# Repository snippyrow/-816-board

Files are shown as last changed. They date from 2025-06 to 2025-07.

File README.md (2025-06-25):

# Retro computer board!


A retro computer motherboard for the W65C816S CPU.
Dual-core expandable, 16mb extended memory, four expansion ports.

## *WHY* did I make this??
I have always loved building things with my hands, especially electronics things. I also love computers, and always to learn how they work. I believe that this is part of that hobby, building myself a computer system to play around with. I want to develop software, as well as expandable hardware. My end goal is to write a complete opertaing system for this build, and have it run DOOM!

# Basic Specifications
The primary core is a W65C816S microcontroller, with 32kb of SRAM. EEPROM Space is only accessible to the primary controller. Each core has its own cache, or SRAM chip. Located in the upper-half of the first page, each is 32kb. If the primary controller wants to access EEPROM, I.E. to copy data to another portion of memory, it only needs to access the lower-half. If the primary wants to access the secondary core cache, it uses the expanded memory space. There are two types of busses: core-only and global. The global bus is arbitrated between the two cores. The primary gets priority, then the secondary. In order for the first to access secondary, it must first disable the secondary core. This allows it to always be able to write. The primary core must not access the secondary core too often, as it must be disabled beforehand. If the secondary core needs to access the main bus, it queues to wait before the primary CPU does an internal cycle. At that moment it will take whatever is in the queue registers. This means that the secondary must not access the main memory too often. The secondary cache is only exposed to the global bus if the primary is using it for a transfer. 

The system is powerful enough to run a basic operating system, and provides options to expand into a workable computer system.

## Advanced
The system uses two cores, the W65C816S core. It is not a drop-in replacement for the W65C02S, and samples data during the falling edge of the PHI2. Each core starts in a 6502-emulation mode, and then transitions to the native '816 mode. Each core can access up to 16MB of memory and has 16-bit internal registers. The primary core contains 32kb of EEPROM space as well as 32kb of SRAM space. The secondary core is disabled at runtime, and must be re-enabled later. The low 65kb of the memory (2^16 bytes worth) are used to communicate and run simple programs. The 32kb space acts as a sort of cache system for each core, and they can communicate largely based on the upper shared memory. Beyond the low 65kb there are devices and expansion memory. The secondary core is unable to reach the primary core, though the primary core can access the secondary core by an expansion device. The first devices after the local memory are the expansion devices. Not only are the expansion ports physically on the board mapped here, but so is the control register for the secondary core, as well as the built-in serial port controller. 

While the primary core is not actively using the global/shared memory, the secondary core is free to do so. To upload a program or start a second process, the secondary core must first be disabled and reset. Then, the cache is accessed and the program is copied. The reset vector will point to some location in the cache, and it will be re-enabled. **Do not set the reset vector elsewhere.**
As stated previously, when the secondary core needs to access shared memory, whether that be an expansion device or general memory, it latches the address. If reading, it sets a control bit and waits for a NMIB. If writing, it sets the control but the other way and latches the write data. When the write is completed, I.E. once the primary is not active, a NMIB signal is sent signaling that the memory transaction was completed. The WAI (wait for interrupt) can be used. 
The system is based off an expanion-type model, where it encourages expansion devices to be built and used. Some examples could be a VGA card, sound card, or a keyboard/mouse system.



## Primary core operation
The core is initiated during a power-on reset phase. The secondary core is disabled during this time, and no secondary transactions are happening. The primary will disable the built-in serial port built in directly to the secondary, and can work without using the secondary core at all. It can use the global bus like the internal core bus.

## Secondary core operation
There are two bits that control the secondary core: ENABLE (0) and RESET (1). The ENABLE bit is used to turn the core on or of. It uses the RDY pin to do this. Enabling this also allows the queue to begin transferring data. The IRQB pin is used for the serial adapter, and the NMIB is used when an external read request has been completed. The RESET pin is used to control the RESB pin on the secondary, to reset it to a known state. It is recommended to disable the core using the ENABLE bit before changing data on the secondary cache. When the primary CPU goes into an internal cycle, it takes whatever value is in the address latches and will attempt a memory transaction. The only accessible area for the secondary is the expansion planes and the expanded memory lanes. The RWB bit will control whether it is reading or writing. Since this all takes a single cycle, timing does not matter. The secondary should not attempt frequent external writes due to speed limitations. The secondary only has access to up to half the expandable memory space, as the last bit is used internally for deciding whether it is reading the MMU register. A NMI also happens after a write, to tell the core that the write succeeded before overwriting the register again.

## Built-in serial adapter
The built-in serial adapter is wired directly to the secondary core IRQB pin. If it should be disabled, it can be done so by accessing the internal registers. It uses the R6551 chip. Does not include RS232. When reading data from the serial port, it must use the R6551 as an expansion device, located in the external memory lane. This is so that it can be externally controlled by the primary core. Attempt to read by accessing the global data bus, and wait for an interrupt on the NMIB pin. WAI can be used. The same goes for sending data.
The secondary should rely in the WAI instruction to manage external reads and writes, but could also be triggered by an IRQB signal from the serial adapter. Internal control should be programmed to prevent this. NMI has priority, after that an IRQB will be sent. The flow should be as follows: first an IRQB signal is sent, then an attempt to read the device will be followed by a NMIB signal. When a NMIB is sent during the IRQB routine, it will cause a nested interrupt to occur, allowing it to service properly. 


# Timing Control
Timing control is critical for this system. When PHI2 (the clock) goes from high to low, it indicated the start of a new cycle. VDA/VPA pins change about half-way during the PHI2 low period, and indicate whether the CPU is undergoing an internal cycle. Write and read cycles are all sampled on the falling edge. When VDA/VPA update shortly after the falling edge, the primary core is disconnected from the global bus, and it prepares to do a transaction by updating the address that was latched before. write data is also placed onto the data bus if necessary. On the next falling edge, data is written or data is read. If read, it then sends a NMI to tell the core that it read the data. From there it will read the data back from a specific register. When using it to read, it does not exactly read directly from the memory devices. Instead, it reads from a memory management unit that waits for the primary core to open. The secondary can read the MMU register, located in the upper half of the expandable memory space (bit 23). In order to disconnect the primary, BE is set high, disconnecting the data and address busses. Afterwards, the latches are turned on. 
Immediately after the bank address is pushed to the data bus, all read data begins to enter through either the cache space or the shared memory space. RDY is toggled by the control of the first bit in the control register, and is only sampled and updated on the following falling edge of the PHI2.

## Examples
If the primary wants to upload something to the secondary, I.E. change the task, it will first disable the core and push it into a reset. This prevent erroneous memory accesses. Then, with the cache mapped as an expansion memory device, begins accessing. The primary is **blocked** from accessing the secondary cache if the core is active. The only way for the two to communicate is through the shared global memory tables. After it is completed, re-enable the secondary.

# Expansion Ports
The machine contains four expansion ports, wired directly to the primary. Two of the slots are larger, and each one of the two is either wired to IRQB or NMIB. The other two are simply expansion devices. The larger ones have A0-A3, and the smaller ones have A0-A1 as register addresses. The shared memory on the global bus is beyond the 65K from the two cores.
The controller for the secondary, the controller for the serial port, and just about everything else is connected in through the expansion device encoder to save on space.

# Physical Board Explaination
### Primary Core
The primary core uses the W65C816S, with a 24-bit address bus and an 8-bit data bus. The highest byte of the address bus (A16-A23) is pushed onto the data bus during the low phase of PHI2, and is latched at the rising edge of the clock. The address bus comes stable around the same time. During these times, all the chips may stabilize into selecting the correct hardware for the write. Each core has a 74HC373 and a 74HC245 to moderate the data bus and the banked address busses. The BE pin will set the data bus, address bus and RWB pins to high-Z. The banked address byte is fed into a chip that detects if it is anything >0x00. This means that an external cycle is being attempted. If not, the selection uses A15 to select from either RAM or ROM to read/write from. In an external cycle, the primary is shut off from the rest of the device. During an external cycle, the full address is passed to the global address bus, and the data is either passed through from the data bus directly or read in through an octal buffer. The RWB pin is multiplexed along with the secondary.
The expansion slots are wired directly into the primary core NMIB/IRQB pins, and are pulled high on the board. 

### Secondary Core
The secondary core has much the same setup as the primary core, but has some key differences. It can work independently of the primary through its own cache, but lacks an EEPROM space. In order to perform an external read/write, when it detects an external memory transaction it always writes to a large set of registers. These registers latch A0-A22, as well as whether it wants to read or write. It may not be necessary for it to use the full 16MB address space. The secondary cache lies outside of the range that the secondary can reach. When it is latched, it also sets a D-flipflop into a HIGH state. The state of the first flip-flop is transferred over to the external memory device selector, which can choose which device to enable. It is only active during either an external cycle made by the primary or the secondary waiting to write/read data. Now that the devices have a stable address, when an external cycle happens, it sets the second flip-flop into a HIGH state. This will immediately reset both back to LOW, but sends a NMI to the secondary processor.
During an external cycle, the secondary processor latches are always pushed out to the global bus, as well as any data. If no core is desiring to read from the global data bus, then it may go floating. If the secondary desired to write previously, that old data would be pushed, otherwise nothing holds on to the data bus. Therefore the global data bus is always pulled LOW.
A15 is always pulled LOW, and in order to *read* data coming from the global busses, any address from 0x0000-0x7FFF will work. It simply takes the place of the EEPROM space. On the secondary the cache is in the upper half rather than lower.
The secondary processor has two control bits, ENABLE and RESET. ENABLE will control the processor state, pausing it and disabling the address/data busses. The RESET bit will cause it to reset back to a known state. The secondary processor will have all of its data and address busses disabled during this time. The cache can be accessed by the primary core processor during this time, while it is disabled. *It cannot access while running.* While the address and data busses are in a High-Z state, the cache can be selected as an expansion device, and the address/data/RWB for the primary processor are pushed in. The secondary local data bus are always pulled LOW. The secondary address bus is always matches the primary address bus while not enabled, as a way to drive it.

#### Serial adapter
As mentioned earlier, the serial adapter is wired directly to the secondary core, and works as any other expansion device would. The secondary should either disable the adapter or mask interrupts if it were to be doing something other than serial work.

#### Memory selector
The memory selector works entirely off the global address busses for selection, choosing serial devices or memory expansion cards. Devices are only selected if either there is an external cycle or the secondary is waiting to write data. 

# Datasheets
https://www.westerndesigncenter.com/wdc/documentation/w65c816s.pdf

# BOM
| Item | Quantity | Price (USD) |
|---|---|---|
| JLCPCB 180x140mm | 5 | $25.15 |
| 10K Resistor | 10 | $1.85 |
| SN74HC373N Latch | 10 | $9.77 |
| W65C816S6PG-14 MPU | 2 | $24.20 |
| L78L33 Regulator | 5 | $1.40 |
| 10uF Capacitor | 5 | $1.15 |
| LED (Red) | 10 | $2.60 |
| SN74HC04N Inverter | 5 | $6.55 |
| SN74HC21N Gate | 4 | $2.60 |
| Tactile Switch | 5 | $1.50 |
| SN74HC245N Transceiver | 10 | $6.22 |
| AT28C256 EEPROM | 1 | $11.62 |
| 150Ω Resistor | 4 | $1.44 |
| AS6C62256 SRAM | 2 | $9.50 |
| 1MΩ Resistor | 4 | $1.44 |
| SN74HC138N Decoder | 5 | $5.50 |
| 1N914 Diode | 5 | $0.50 |
| SN74HC10N Gate | 4 | $2.52 |
| 10kΩ Resistor | 20 | $0.30 |
| 1kΩ Resistor | 10 | $0.27 |
| SN74HC32N Gate | 4 | $2.20 |
| SN74HC688N Comparator | 6 | $8.52 |
| 4.7kΩ Resistor | 10 | $0.47 |
| SN74HC126N Buffer  | 4 | $2.64 |
| SN74HC00N Gate | 5 | $3.00 |
| 2N3904 Transistor  | 10 | $0.77 |
| 30pF Capacitor | 10 | $1.18 |
| 0.1uF Capacitor | 100 | $4.00 |
| 1MHz Oscillator | 2 | $6.90 |
| SN74HC08N Gate | 4 | $2.40 |
| SN74HC74N Flip Flop| 4 | $3.60 |
| 20-pin Socket | 24 | $3.10 |
| 16-pin Socket | 20 | $2.42 |
| 14-pin Socket | 20 | $2.20 |
| 28-pin Socket | 6 | $3.84 |
| 40-pin Socket | 4 | $3.68 |

**Total: $167.00**

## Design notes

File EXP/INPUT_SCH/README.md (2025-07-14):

# Computer input controller
Like all computers, I need a way for the user to send input to the machine.

## Features
This device has the ability to send and receive commands to PS/2 devices, including keyboards and mice. To switch between the two, special commands can be sent that are interpreted by both devices.

Two ports are included: one for a keyboard and one for a mouse. May or may not be colroed, but text underneath will specity. Each port has two registers that can be accessed by the system, as well as a status register:
| Vector | Name |
| --- | --- |
| 0x0 | KBD Send |
| 0x1 | KBD Recv |
| 0x2 | Mouse Send |
| 0x3 | Mouse Recv. |
| 0x4 | Int. Status |

When either a keyboard or mouse port receive a packet, it sends a signal along the IRQB line on the main core. If it misses a packet, it will be overwritten with the next one and cannot be recovered. The interrupt status register is as follows:

`ECCCPPMK`

The first bit read from this register declares whether the keyboard has sent the interrupt. The next bit declares if the mouse has sent the interrupt. If both are high, then both devices have sent the interrupt at the same time. If this happens, both packets are preserved in each register. The third bit in each register is the result of each parity bit from the ports. It is also overwritten on the next packet. The third bit is for the keyboard parity, and the fourth is for the mouse parity. If a parity errors happens, send another command to the respective device to re-send the command.

When reading each received packet data register, the interrupt returns to zero in the status register. For examples, reading 0x1 makes the first bit go to zero.
Sending commands happens in hardware, without need for system intervention. The PS/2 clock signal for each port is derived from the system clock, being divided by a value selected in the three C bits. These three C bits are the only writable bits in the control register, and go towards a decoder. It can select from 1/16 system speed up to 1/2048 speed. This is important because this system can take advantage of a wide range of clock speeds, and this would mess with the PS/2 bus speed. It must be around 10-20khz. If the divisor is set larger, then the host must write commands slower. If it takes 11 bits per packet, at 16 block cycles per bit, then the host must not send another command for 176 clock cycles. For 1mhz (1/64), that increases to about one every 700 cycles.

The host CAN send a command to a mouse within this timeframe, and both are sent and received independantly.

The E bit in the control register can be set to 0 to disable the input card, which is set to at default. This disables the IRQB line on the card, allowing another device to use it if needed.

Receiving packets happen asynchronously, as the CLK/DATA lines are usually pulled high by a resistor. When CLK first goes low, it triggers a capacitor to quickly charge and slowly discharge. Data is latched on each clock falling cycle, into a shift register. There are two 8-bit registers to hold all of the bits (11), and the parity bit is outputted in the control register when read. After the packet is completed, the capacitor will discharge and set a latch. This is OR'd with keyboard/mouse latches, so both must be acknowledged before the line goes dead. Sending commands also happens over hardware. Data is written into the register by the system, and a counter is reset. Two decoders are set to send the start bit, packet byte, parity and stop bit. Probably will be two 74HC238's. After the counter is over a certain value (11), the bus stops pulsing the CLK signal and the DATA bus is permanently released. The counter is ticked on every divided clock pulse. Pairty is computed in hardware against the contents of each input register automatically. By the time all the bits are sent, the parity computation will be completed. Parity is computed against an 8-bit number using eight XOR gates, or a single 8-input XOR gate.

Alternativly, use a 74HC280 to generate odd parity. It implements everything internally. In order to handle the counter properly, implement a 4-input NAND or AND gate to check 0b1010 (10) and stop the counter from going any further. ALso run that to block the CLK from being changed. Data should be updated on the DATA bus after the rising edge of the CLK and will be latched by the device during the falling edge.

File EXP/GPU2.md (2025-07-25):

# What happened??
The timings may be too tight with the original design, being forced to act in under 20ns. The fix is that instead of using each VGA pixel cycle to write data and preload, use four cycles to write and four to preload. This is good because it has MUCH longer to act, and I can therefore use a more covnentional 128k x 8 SRAM. It can easily act within 55ns, unlike the 12ns one.

## Advancements?
The first half of the 8-cycle period is for writing data. The multiplexers are set to the addresses in the registers, and a writing state is initialized. This will take upwards of 40 x 4ns, or 160ns. This is well within the allowed time. When powering up the card, the preload register is initialized to 0x00. The preload phase is on the other half, directly controlled by X2. WHen in the preload phase, it is set to read mode, and the address is switched to the counters. At the same time, the latch is enabled, allowing the data to be laoded. Since this is technically happening half way through the byte, everything will be shifted over some. To prevent the slow access time from bugging out some pixels, the data is only committed at the last cycle. Software should be able to counteract this.

## What works?
The signal generation works well, as it is within the allowable timeframe. I suspect that the main cause was the slowness of the 74LS20 chip, though I can't know for sure. The only way to test it for certain is to buy a 74HC/AC20 and plug it in. Overall the timing may be too restrictive for these chips, and in that case it may be worth it to simply convert over to the less harsh design. It may use more board space however, specifically around the control section. If the user decides to change the X/Y coordinate immediatly before the writing of the data, and a timing contention happens, nothing bad happens. If the address is late, it will simply write the old data into the new location. It will almost instantly be overwritten next phase.

## Extra parts
The previous design used a NAND and a 4-input NAND to control the operation. Instead, Alternate read/write cycles by using X2, which should be fast enough. A 3-input AND gate can be used to time the latching circuit, taking in X0, X1, X2. it would it irrespective of the clock phase.

## Conclusion
The write phase will not collide with the read phase at all, and this allows for better timings. Since each stage has 160ns to act, that is WAY more than enough time to work. The main focus is the preload time, which is arguably the most vital step. It allows three cycles, or 120ns, to read. This can then be latched, and since it is mostly irrespective of clock, takes 40ns. This is good enough. Things will be shifted over by one, since it will technically be loading the previous set of pixels and then displaying them later. Either software can shift, or nothing happens at all. Everything is shifted over by 7-8 pixels, and it should be basically invisible to the user.

# Oscilloscope

The oscilloscope likes to smooth off bad edges, and timing issues are a major cocern. It may not be rated for these sorts of speeds, though should do fine for now. The circuit works in theory, but in practice the timings are impossible.

## Practical circuit application
The signal generator will be exactly the same as before. Six comparators get the start and end of each sync pulse, as well as the time tk reset to the Y counter. These go into a flip-flop, to maintain the state of each sync pulse. They also go into inverters for the counter control logic. The counters are updated on the falling edge of the vga clock. The registers are also the same, as timing is not an issue. A 74HC238 decoder is updated for each one, and is managed by the device select, PHI2, and the RWB signal. The multiplxers for the address are tied between the pixel counters and the user-defined locations. These are always outputting and are controlled by the X2 bit. If X2 is low, enable the user-defined registers. Otherwise, define the pixel counters during preload. These technically change every 160ns, giving the SRAM plenty of time. The SRAM is an HM628128 with a 55ns access time. Both chip selects are ON, and it is toggled between OEB and WEB. OEB/WEB signals are defined by the X2 bit again, so it is always complimentary and very stable. A three-input AND gate is used to control the latching of the preload register, and that register feeds in to an 8-1 multiplexer. That is controlled by X0, X1, and X2. The frame select is not time-dependant that much, and the architecture can be carried over. The only difference is the added latch enable controller, which uses a 3-input AND. When the clock goes over into the next byte, latching is disabled and the addresses are switched. Since it is controlled directly by fast counters, the latch should disable itself faster than the addresses are able to switch over.

## Action
Test for any other abnormalities, order a 74HC20 or 74AC20. While doing so begin construction on the new design using breadboards. Signal encoders make 3 boards, ram/output logic makes 1, everything else 1 so five boards. Use jumpers to build, test each one for connection issues.

## NEW
The timing will work slightly differently now. Each pixel cycle is roughly 40ns, and the RAM has a 55ns access time. The address is not looked-ahead at all, to save board space. During the first-half of each byte cycle, the CPU has access to write data to the RAM. During the second half, the video circuitry has access. Since the data is only latched at the last pixel cycle, the data displayed will be eight pixels dragged forward. This results in a thin black section on the left, and some text going off on the right. This can be corrected in software. During the first cycle, AKA when X0-X2 is 0b000, the SRAM is switched into a writing mode.

On the first cycle the address bus is changed to the correct data, and the data bus is updated. At the same time the OEB bit is set HIGH. During the second cycle the WEB bit is set LOW. This state repeats for another cycle. During the fourth cycle the WEB bit goes HIGH, and the OEB bit goes LOW. The data bus will disengage as well. On the fifth cycle the address bus will change to the pixel address that is required. On the eighth cycle the data is latched into the 74HC165 register. This will lead right into the next byte cycle, where OEB goes HIGH. The counters are updated on the FALLING edge of the pixel clock!

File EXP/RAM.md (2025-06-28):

# Expansion RAM Module



## What is it?
This is a special module made for my custom motherboard. It can hold exactly 2^21 bits of information, or around 2MB. The motherboard has space for two of these modules, adding up for a total of 4MB. USing the breakout pins, up to 16MB can be added. The board would just be too large.

## How does it work?
The module contains four AS6C4008 SRAM chips. Each one has an access time of about 55 nanoseconds, making it quite fast. Each chip can store 512KB of data, four of them adding up to 2MB. It works virtually the same as the cache memory directly soldered to the motherboard, just larger. The controller system is also quite simple. One first chip is a 74HC138, which selects the correct chip in the module. It uses pins A20-A21 to define which one it needs. The second one controls whether to read or write from the selected chip. as defined by the PHI2 and RWB pins on the expansion slot. It also comes with a large capacitor built into the module. As to prevent random data los due to pwoer fluctuations. While each memory chip has built-in protections, it's best to use extra security if there is enough board space. It also comes with a power LED, telling the user the right orientation and whether it's connected to power.

## How do you use it?
The module expands away from the expansion cards, which are themselves supposed to stretch backwards. That way, they don't hit each other during installation! The edge connector I used provides enough friction to hold the cards in place.

## Extra images



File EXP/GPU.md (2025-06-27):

# Custom-made GPU

A standard 640x480 VGA-generating GPU for my computer build, as listed in the parent directory. Having only one bit per pixel for color, this makes it extremely useful for rendering a text display.

## Why did I build this?
I think that every computer should have a graphical output of some form, and this is as simple as it gets. This expansion board will allow me to do a lot of cool things with my project.

## Explaining the inner workings


The card uses a 640x480 60hz resolution, running over a standard VGA cable. This can be converted with a dongle to HDMI or DisplayPort. The card has four registers: pixel location X, pixel location Y, data write register and control register.
Since the card uses one bit per pixel, there can be eight pixels stored in a single byte of VRAM at once. Therefore, you can write eight pixels are once, going left to right. A standard text display has each character being 8x16 pixels in size, so you can perfectly write in each character using 16 different write cycles. The text resolution is 80x30 characters, fitting inside a 640x480 text display. This is certanly not limited to text, just optimized for it. You can use a dithering algorithm to draw in more advanced graphics and images.
The pixel X register actually moves the pixel selector 8 pixels at a time, and you can selectively write bits for each one. It also supports basic double buffering, since it uses a single 128k x 8 SRAM module. 640x480 uses less than half of the space, so the highest-most but is used to select the frame. The user can write to a back frame before switching them. It is then automatically switched at the end of each frame. Pixels are preloaded every eight cycles, and is kept track of using the X counter, which keeps track of which pixel is being displayed at any time. During the first low phase of the clock, the addresses are changed from the user-defined addresses to the ones found in the counters, and the RAM is outputted to store eight pixels are a time. In between these preloading phases the user writes pixel data to the back frame. If the CPU can handle a maximum of 100,000 writes per second to the GPU (very slow), then the actual data is 800,000 pixels per second, and 640 * 480 is about 300,000 pixels. Therefore it is quite fast for a text display, and can easily hit several frames per second on a slow speed. The card automatically generates frames without any user input, is completely asynchronous from the main board and is optimized for holding a frame long-term.

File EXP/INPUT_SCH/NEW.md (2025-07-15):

# Single-port keyboard handler

This is a basic handler for a single PS/2 active keyboard. The device has the ability to both send and receive commands.

The PS/2 bus works as follows: The DATA pin is controlled by both the host and the device, but the CLK pin is usually controlled by only the device.
When reading a packet from the PS/2 device, a capacitor is charged whenever the CLK line goes low. Data is latched on every LOW clock edge, and the capacitor is allowed to discharge slowly.
After the entire packet is sent, the capacitor will begin to slowly discharge.
Once it reaches a certain theshold, the capacitor will activate a signal that will trigger the IRQB pin.
Since the lines for sending and receieving commands are shared, a control system will be implemented to prevent the receiver register from being overwritten. Also to prevent erroneous interrupts.

## Sending packets
Sending commands must be followed by a specific sequence of steps. To begin sending, the host must pull the CLK lane LOW for >100us. To do this, use a monostable multivibrator to pull it low. This is the only time that the host will pull the clock lane low. Usually when a packet is received, it would go through a latch ticking high for a moment, but that action is inhibited at the moment a transaction is started. Due to various CLK speeds, a second capacitor system is set up. At the first clock pulse, and if the writing register is written, a signal goes LOW that inhibits the interrupt register. This has an interval LONGER than the first chain, meaning that no interrupts are triggered. Once it gets re-enabled, it allows it to send interrupts again. As a product of this, the incoming register gets voerwritten by the new data. This should not be an issue, since input registers should always be read from at the moment of an interrupt.

Data is latched by the device on the RISING edge of the CLK lane, and data should be updated on the FALLING edge. A 4-bit counter is for selecting each data bit to send in a packet. There are: START (0), byte, parity, STOP (1). When a write is issued, the CLK lane is pulled. When the interval is over, the counter will have been reset to zero, and it can pull the data ane LOW for the start bit immediatly. SInce the release of the CLK lane will be detected as a rising CLK edge, the counter will try to update to one. Therefore place everything one bit higher than expected. The counter should go into two 8-1 multiplexer ICs, This will select the correct bit to be sent. The counter should be disabled after the packet is sent, as an incoming packet will cause it to roll over and cause contention. Therefore when the counter exceeds 11, disable any future counting. 

## Host parity
PS/2 Uses ODD parity, and a 74HC280 should be sufficient to do this. It is added on after the data byte and is computed immediatly on the contents of the outgoing register. When the system attempts to write data, at the moment CLK is pulled LOW, the counter selecting each data bit is reset. During this initial pull-down phase, the card will not be allowed to pull the data bus.

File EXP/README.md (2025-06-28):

# Custom computer expansion cards!



A collection of expansion cards I plan to build for my custom dual-core W65C816S motherboard. Two examples include: a basic text-based graphics card, and some 2MB RAM modules.

## Why Did I Build These?
A computer without a graphical display, or RAM sticks is pretty useless. You can run some basic algorithms, but that's about it. These pieces of customized hardware will *drastically* improve that this build can do. For more information, please see the parent directory for the main build.

# About
# If you want to see specifics for each expansion card I plan to build, see the directories listed here in this folder.

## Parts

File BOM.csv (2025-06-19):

NAME | QTY# | COST (USD) | SOURCE
PCB – 4 Layer 180mmx140mm JLCPCB | 5 | $25.10 | JLCPCB
0.1uf 1206 SMD Capacitor | 20 | $2.19 | MOUSER
SMD 1206 Diode | 2 | $1.10 | MOUSER
EDGE CONN 24P | 5 | $4.64 | ALIEXPRESS
EDGE CONN 20P | 5 | $4.17 | ALIEXPRESS
1206 SMD 10K RES. | 25 | $2.56 | MOUSER
RESISTOR NETWORK 10K | 5 | $1.83 | MOUSER
W65C816S | 2 | $26.94 | MOUSER
74HC08 | 2 | $1.10 | MOUSER
AS6C62256 | 2 | $10.57 | MOUSER
74HC373 | 2 | $3.59 | MOUSER
74HC245 | 9 | $7.23 | MOUSER
74HC74 | 2 | $3.52 | MOUSER
AT28C256 | 1 | $12.94 | MOUSER
R6551 | 1 | OWNED | N/A
3.3V/5V Regulators | 5 | $1.46 | MOUSER
74HC32 | 1 | $1.42 | MOUSER
74HC688 | 3 | $4.75 | MOUSER
74HC00 | 1 | $1.59 | MOUSER
74HC04 | 2 | $2.92 | MOUSER
74HC14 | 1 | $1.83 | MOUSER
74HC126 | 1 | $1.69 | MOUSER
74HC138 | 2 | $4.12 | MOUSER
74HC10 | 1 | $1.61 | MOUSER
1.8432MHZ | 1 | OWNED | N/A
1MHZ | 1 | $3.69 | MOUSER
SHIPPING | 1 | $14.60 | MOUSER
TOTAL |  | $148.12

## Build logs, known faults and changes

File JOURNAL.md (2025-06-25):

---
title: "65816 Retro Motheroard"
author: "snippyrow"
description: "A retro computer motherboard designed for the 65816 CPU."
created_at: "2025-05-24"
---

# May 28th: Began laying out PCB!

For the past few weeks I worked on the schematic, going from a quad-core to a dual-core architecture. I had to cut back and expand on several ideas, though it all seems to work according to the datasheets!
Snapshot_2025-05-28_17-15-16

Snapshot_2025-05-28_17-15-46

**Total time spent: ~12h**

# May 29th: Finished laying out PCB

Finished laying out the custom PCB. In the process I removed one of the expansion RAM slots to save on board space, bringing the total amount of expandable memory down to 6MB. Additionally I removed the decoupling capacitors connected to the RAM, as I believe they take up too much space and can be easily added to the individual expansion sticks.



**Total time spent: 3h**

# May 31st: Updated PCB Layout Again..

After checking the design voer, I realized that improvements could be made. Added mounting holes around the corners, as well as the implementation of a serial port directly on the main board. While it does not use RS232, it uses an arduino-compatable 0/5V signal. The 4-pin header comes with a 5V supply pin, allowing a device to expand it out to any type of standard required. Serial connects into the secondary core directly, allowing it to take some of the load off the main CPU. Appears like an expansion device on the BUS.




**Total time spent: 3h**

# June 7th: Finished Major Re-design

I discovered an issue in my original design, the system that enabled the secondary processor was faulty and would never enable it properly. I also discovered issues with the way the primary CPU writes data to memory, as it would sample data on the wrong half of each cycle. This would cause severe issues. Additionally I decided to change up the design of the system, giving each processor 32kb of cache. This way each co-processor can work fully independantly of the other, only needing to halt in case it needs to access the global memory bus, which exists outside the first 65k. I also wrote a ton of documentation in the README.md file, which extensively explains how the board works.



**Total time spent: 9h**

# June 11th: Half-way there!

I looked over the entire schematic, checking it twice, and began laying out my new PCB. All good things must come to an end, and it doesn't look as nice as the other one yet. I changed it to use mostly through-hole ICs to make it look more "retro", as well as being easier to prototype with.



**Total time spent: 2h**

# June 13-14th: Almost done..

I spent this time completing the board layout in the kicad designer, as well as checking the schematic again. I found a few small issues and correct them, though I will probably need to check things one more time before completion. I changed it to have only *two* RAM expansion cards, at 2MB each. This leaves it with 4MB of RAM + expansion cards + local cache. I have put everything into an auto-router, which is going as I write this. I think that I will need to spend a lot more time fixing some of the artifacts of the process, though this is *far* faster than doing it manually.





**Total time spent: 4h**

# June 16-18th: FInal checks

I sepent the last bit fixing some minor hardware bugs, as well as completing the PCB layout and tracing. The kicad ERC returns zero errors, so at this point it's pretty much done and ready to run a program. It's been a great journey, and now I just need to do the tedious work of fixing all the autorouting artifcats. This includes right-angled corners and useless trace geometry. I really hope this project works out! The final size is 180x137mm. Unfortunatly checking a project like this for errors takes a lot of time, so more issues may come to light in later revisions.




**Total time spent: 5h**

**June 23rd: A minor upset**
After joining a forum and asking some questions about my design, I realized that I had done some things incorrectly. I was latching data during the falling edge of PHI2, which in hinesight was incorrect. Due to this I had to change some of my labels as well as switching out most 74HC374's with 74HC373's instead. These work better with the regular bus timings. The pins are almost indentical, so it was a quick fix. I also added some stability by making the address decoding logic check the VDA/VPA pins to see if the bus is valid. This will demand a re-layout and new routing run on the PCB, which should not take long. The price for the project should not change much.



**June 24th: COntinuation**
I completed the board layout and routing process, as well as correcting some minor fixes. The board will soon be production ready, the only thing left is to add more comments to the silkscreen layer.




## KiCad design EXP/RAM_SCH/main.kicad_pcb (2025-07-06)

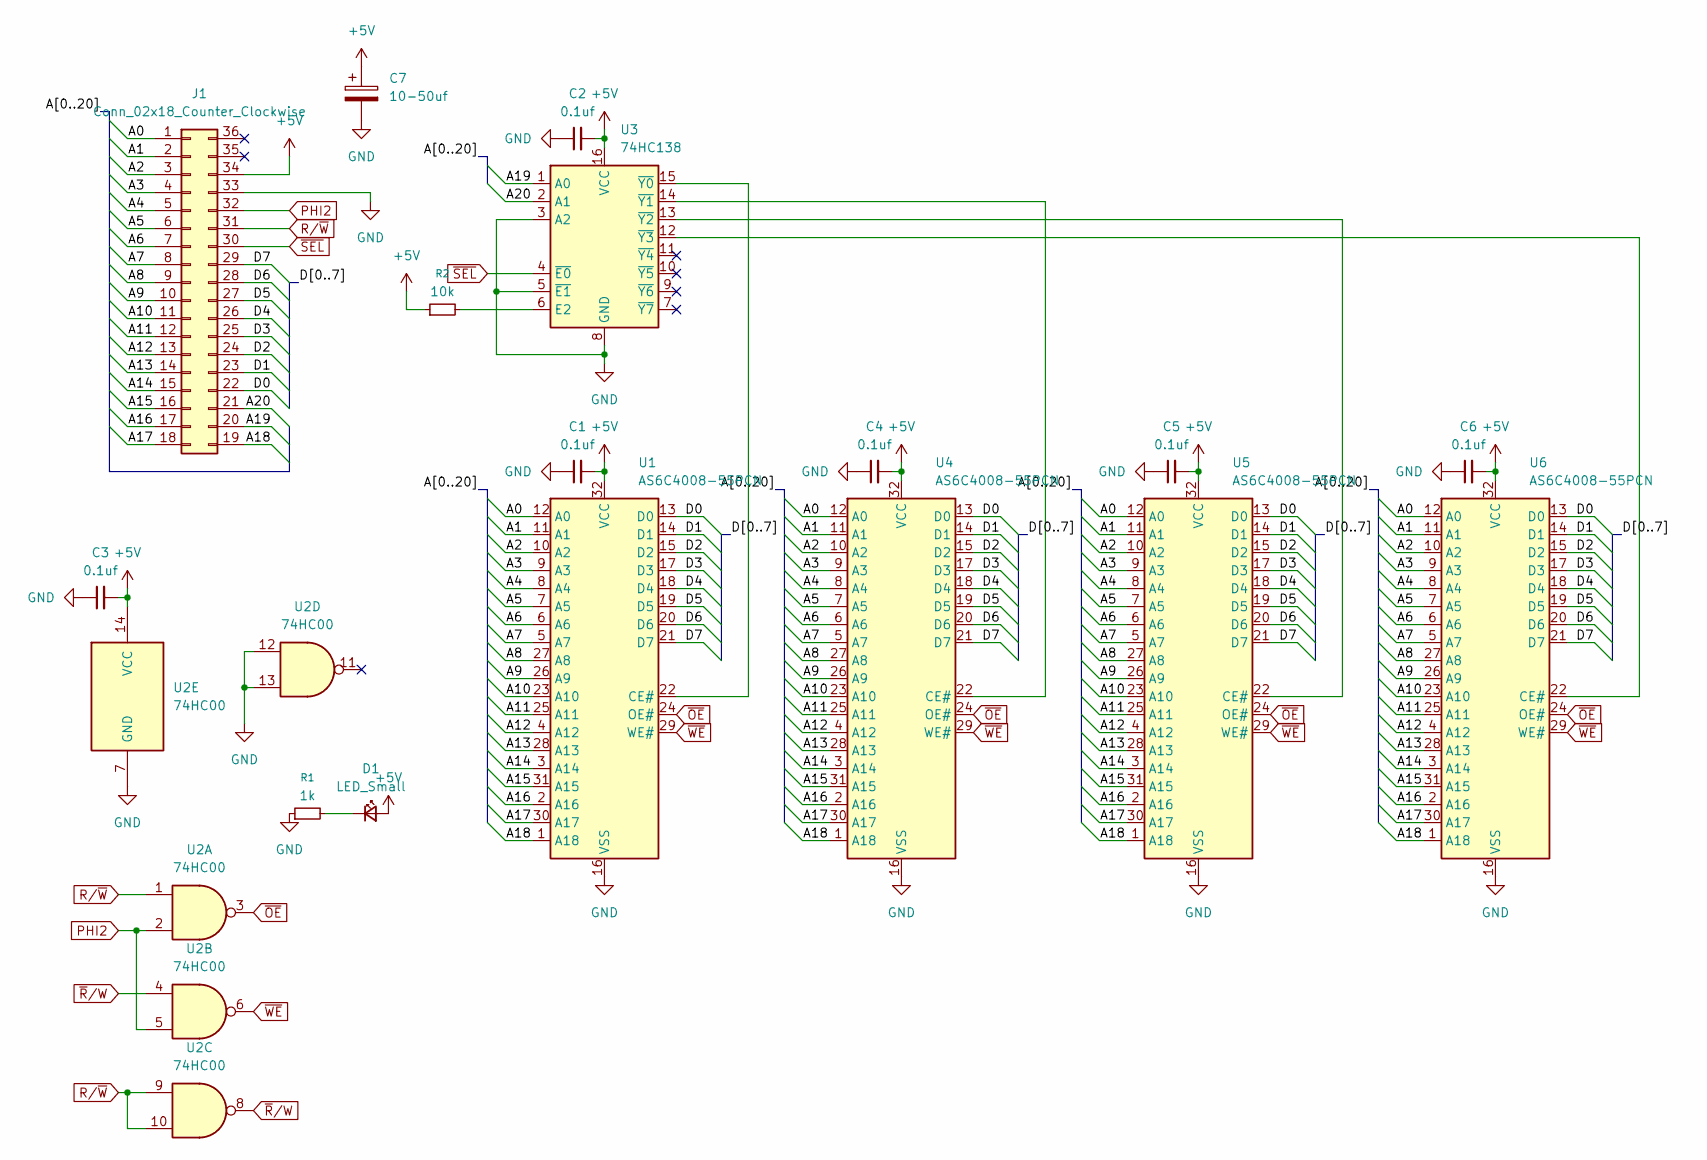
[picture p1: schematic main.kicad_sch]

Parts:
C1, C2, C3, C4, C5, C6: 0.1uf; C_Disc_D5.0mm_W2.5mm_P5.00mm
C7: 10-50uf; CP_Radial_D6.3mm_P2.50mm
D1: LED_Small; LED_D3.0mm
J1: Conn_02x18_Counter_Clockwise; AliExpress_36Edge
R1: 1k; R_Axial_DIN0204_L3.6mm_D1.6mm_P5.08mm_Horizontal
R2: 10k; R_Axial_DIN0204_L3.6mm_D1.6mm_P5.08mm_Horizontal
U1, U4, U5, U6: AS6C4008-55PCN; DIP-32_W15.24mm
U2: 74HC00; DIP-14_W7.62mm_Socket
U3: 74HC138; DIP-16_W7.62mm_Socket

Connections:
+5V: C1.2, C2.2, C3.2, C4.2, C5.2, C6.2, C7.1, D1.2 (A), J1.34, R2.1, U1.32 (VCC), U2.14 (VCC), U3.16 (VCC), U4.32 (VCC), U5.32 (VCC), U6.32 (VCC)
/A0: J1.1, U1.12 (A0), U4.12 (A0), U5.12 (A0), U6.12 (A0)
/A1: J1.2, U1.11 (A1), U4.11 (A1), U5.11 (A1), U6.11 (A1)
/A2: J1.3, U1.10 (A2), U4.10 (A2), U5.10 (A2), U6.10 (A2)
/A3: J1.4, U1.9 (A3), U4.9 (A3), U5.9 (A3), U6.9 (A3)
/A4: J1.5, U1.8 (A4), U4.8 (A4), U5.8 (A4), U6.8 (A4)
/A5: J1.6, U1.7 (A5), U4.7 (A5), U5.7 (A5), U6.7 (A5)
/A6: J1.7, U1.6 (A6), U4.6 (A6), U5.6 (A6), U6.6 (A6)
/A7: J1.8, U1.5 (A7), U4.5 (A7), U5.5 (A7), U6.5 (A7)
/A8: J1.9, U1.27 (A8), U4.27 (A8), U5.27 (A8), U6.27 (A8)
/A9: J1.10, U1.26 (A9), U4.26 (A9), U5.26 (A9), U6.26 (A9)
/A10: J1.11, U1.23 (A10), U4.23 (A10), U5.23 (A10), U6.23 (A10)
/A11: J1.12, U1.25 (A11), U4.25 (A11), U5.25 (A11), U6.25 (A11)
/A12: J1.13, U1.4 (A12), U4.4 (A12), U5.4 (A12), U6.4 (A12)
/A13: J1.14, U1.28 (A13), U4.28 (A13), U5.28 (A13), U6.28 (A13)
/A14: J1.15, U1.3 (A14), U4.3 (A14), U5.3 (A14), U6.3 (A14)
/A15: J1.16, U1.31 (A15), U4.31 (A15), U5.31 (A15), U6.31 (A15)
/A16: J1.17, U1.2 (A16), U4.2 (A16), U5.2 (A16), U6.2 (A16)
/A17: J1.18, U1.30 (A17), U4.30 (A17), U5.30 (A17), U6.30 (A17)
/A18: J1.19, U1.1 (A18), U4.1 (A18), U5.1 (A18), U6.1 (A18)
/A19: J1.20, U3.1 (A0)
/A20: J1.21, U3.2 (A1)
/D0: J1.22, U1.13 (D0), U4.13 (D0), U5.13 (D0), U6.13 (D0)
/D1: J1.23, U1.14 (D1), U4.14 (D1), U5.14 (D1), U6.14 (D1)
/D2: J1.24, U1.15 (D2), U4.15 (D2), U5.15 (D2), U6.15 (D2)
/D3: J1.25, U1.17 (D3), U4.17 (D3), U5.17 (D3), U6.17 (D3)
/D4: J1.26, U1.18 (D4), U4.18 (D4), U5.18 (D4), U6.18 (D4)
/D5: J1.27, U1.19 (D5), U4.19 (D5), U5.19 (D5), U6.19 (D5)
/D6: J1.28, U1.20 (D6), U4.20 (D6), U5.20 (D6), U6.20 (D6)
/D7: J1.29, U1.21 (D7), U4.21 (D7), U5.21 (D7), U6.21 (D7)
GND: C1.1, C2.1, C3.1, C4.1, C5.1, C6.1, C7.2, J1.33, R1.1, U1.16 (VSS), U2.7 (GND), U2.12, U2.13, U3.3 (A2), U3.5 (~E1), U3.8 (GND), U4.16 (VSS), U5.16 (VSS), U6.16 (VSS)
unnamed: D1.1 (K), R1.2
unnamed: U1.22 (CE#), U3.15 (~Y0)
unnamed: R2.2, U3.6 (E2)
unnamed: U3.14 (~Y1), U4.22 (CE#)
unnamed: U3.13 (~Y2), U5.22 (CE#)
unnamed: U3.12 (~Y3), U6.22 (CE#)
PHI2: J1.32, U2.2, U2.5
R/~W: J1.31, U2.1, U2.9, U2.10
~OE: U1.24 (OE#), U2.3, U4.24 (OE#), U5.24 (OE#), U6.24 (OE#)
~R/W: U2.4, U2.8
~SEL: J1.30, U3.4 (~E0)
~WE: U1.29 (WE#), U2.6, U4.29 (WE#), U5.29 (WE#), U6.29 (WE#)

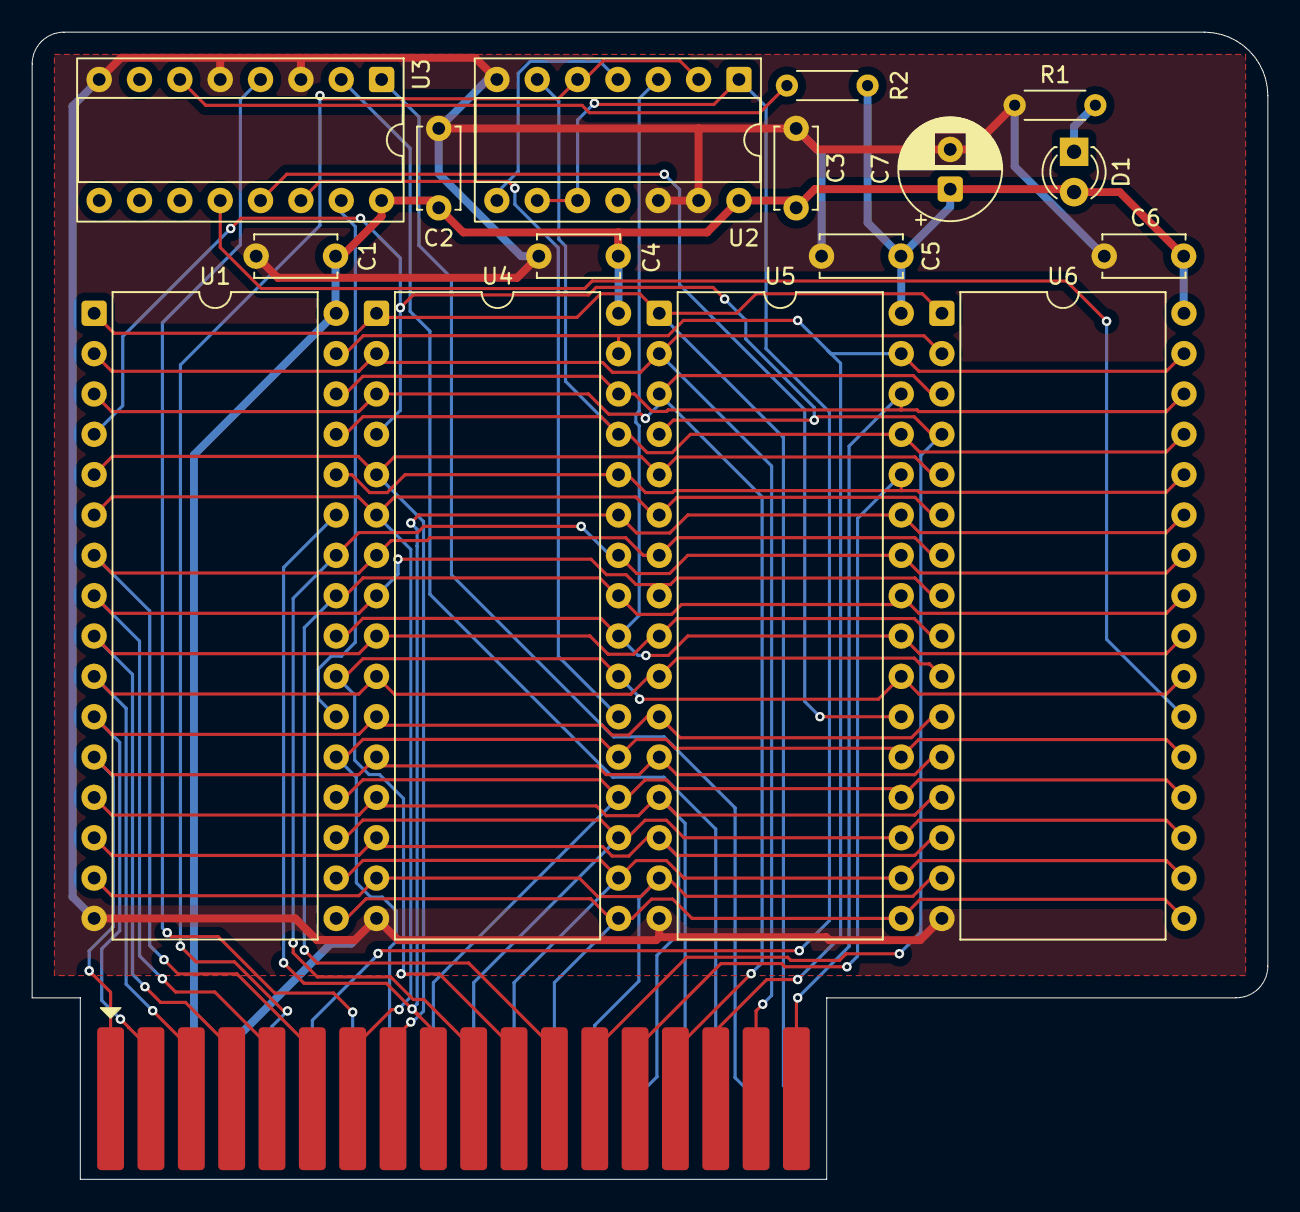
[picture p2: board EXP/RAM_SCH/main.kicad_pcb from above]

Board: 2 copper layers, 77.8 x 72.2 mm, 17 parts (0 on the bottom side), 43 nets.

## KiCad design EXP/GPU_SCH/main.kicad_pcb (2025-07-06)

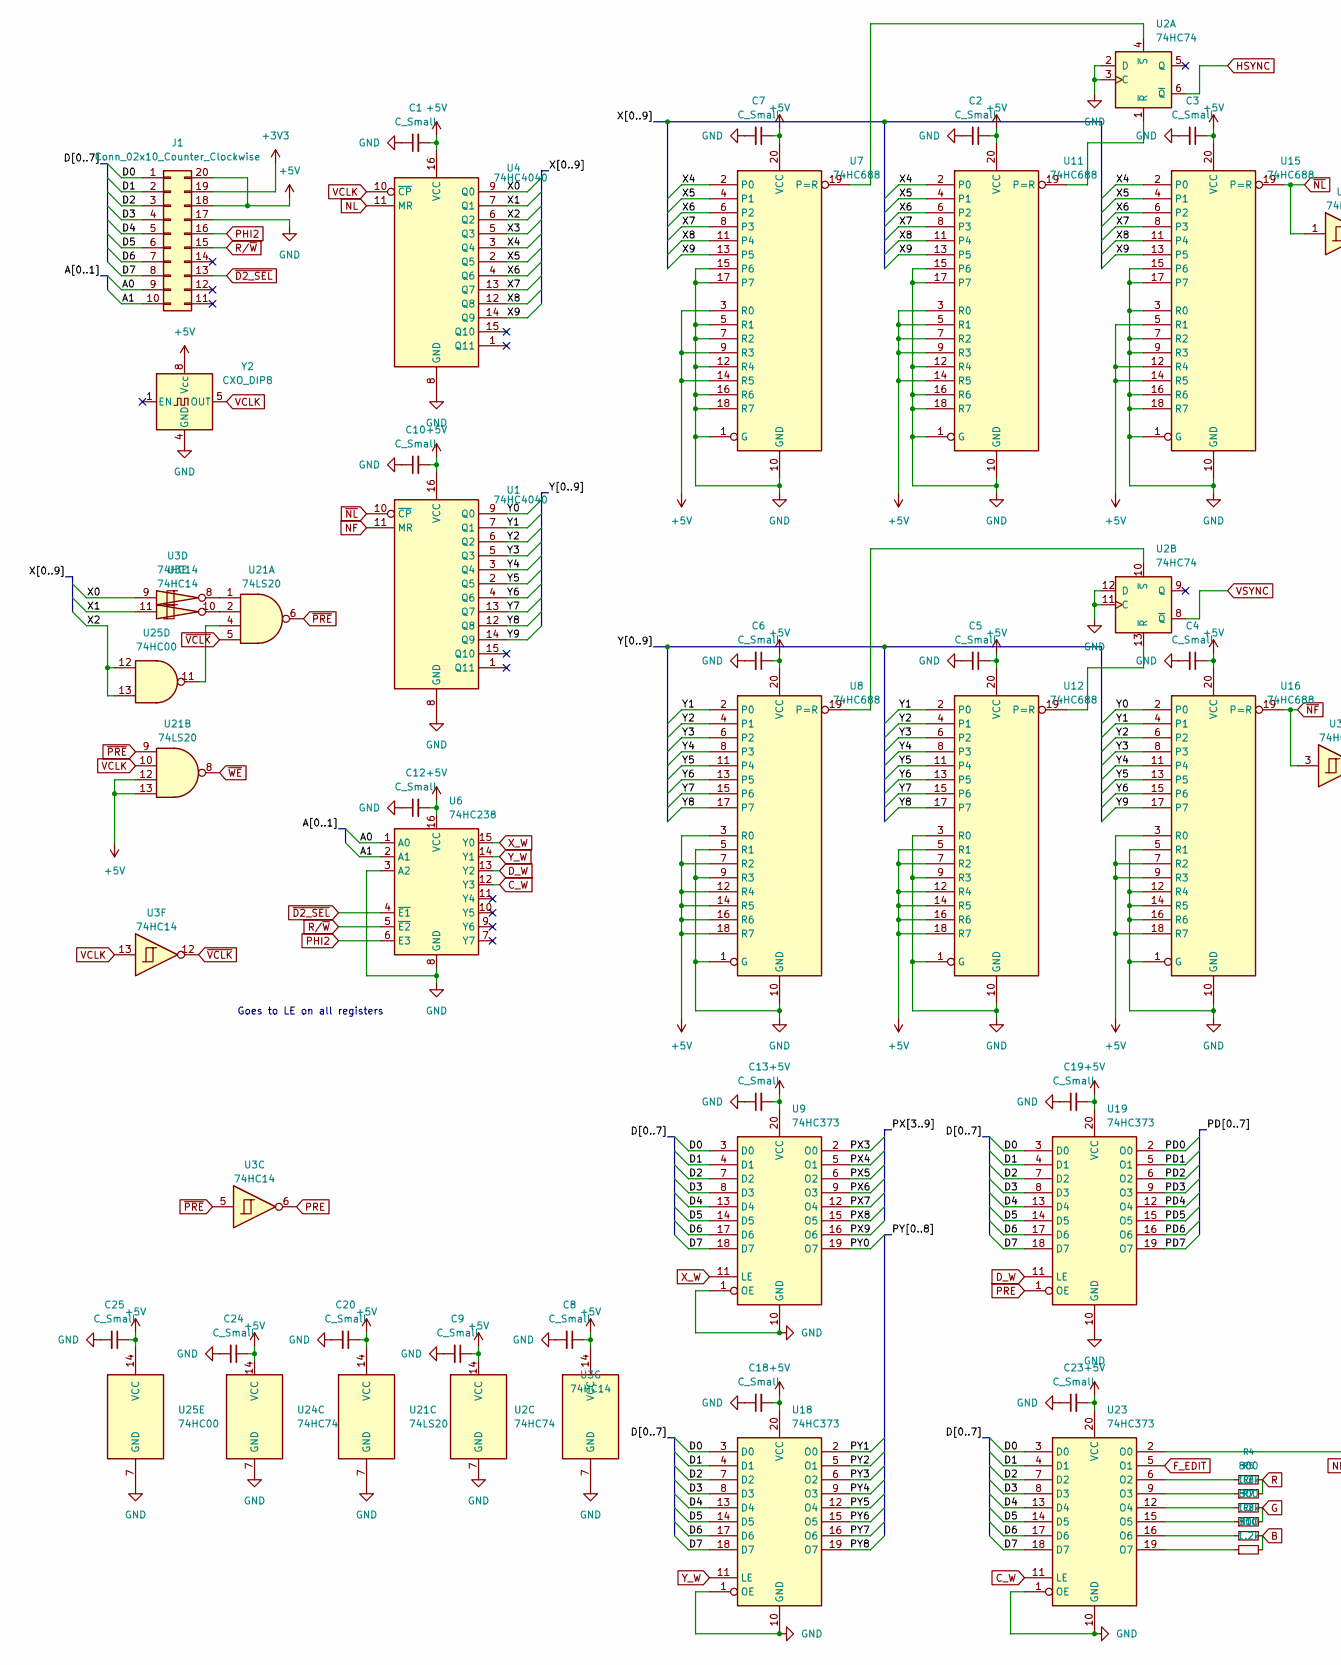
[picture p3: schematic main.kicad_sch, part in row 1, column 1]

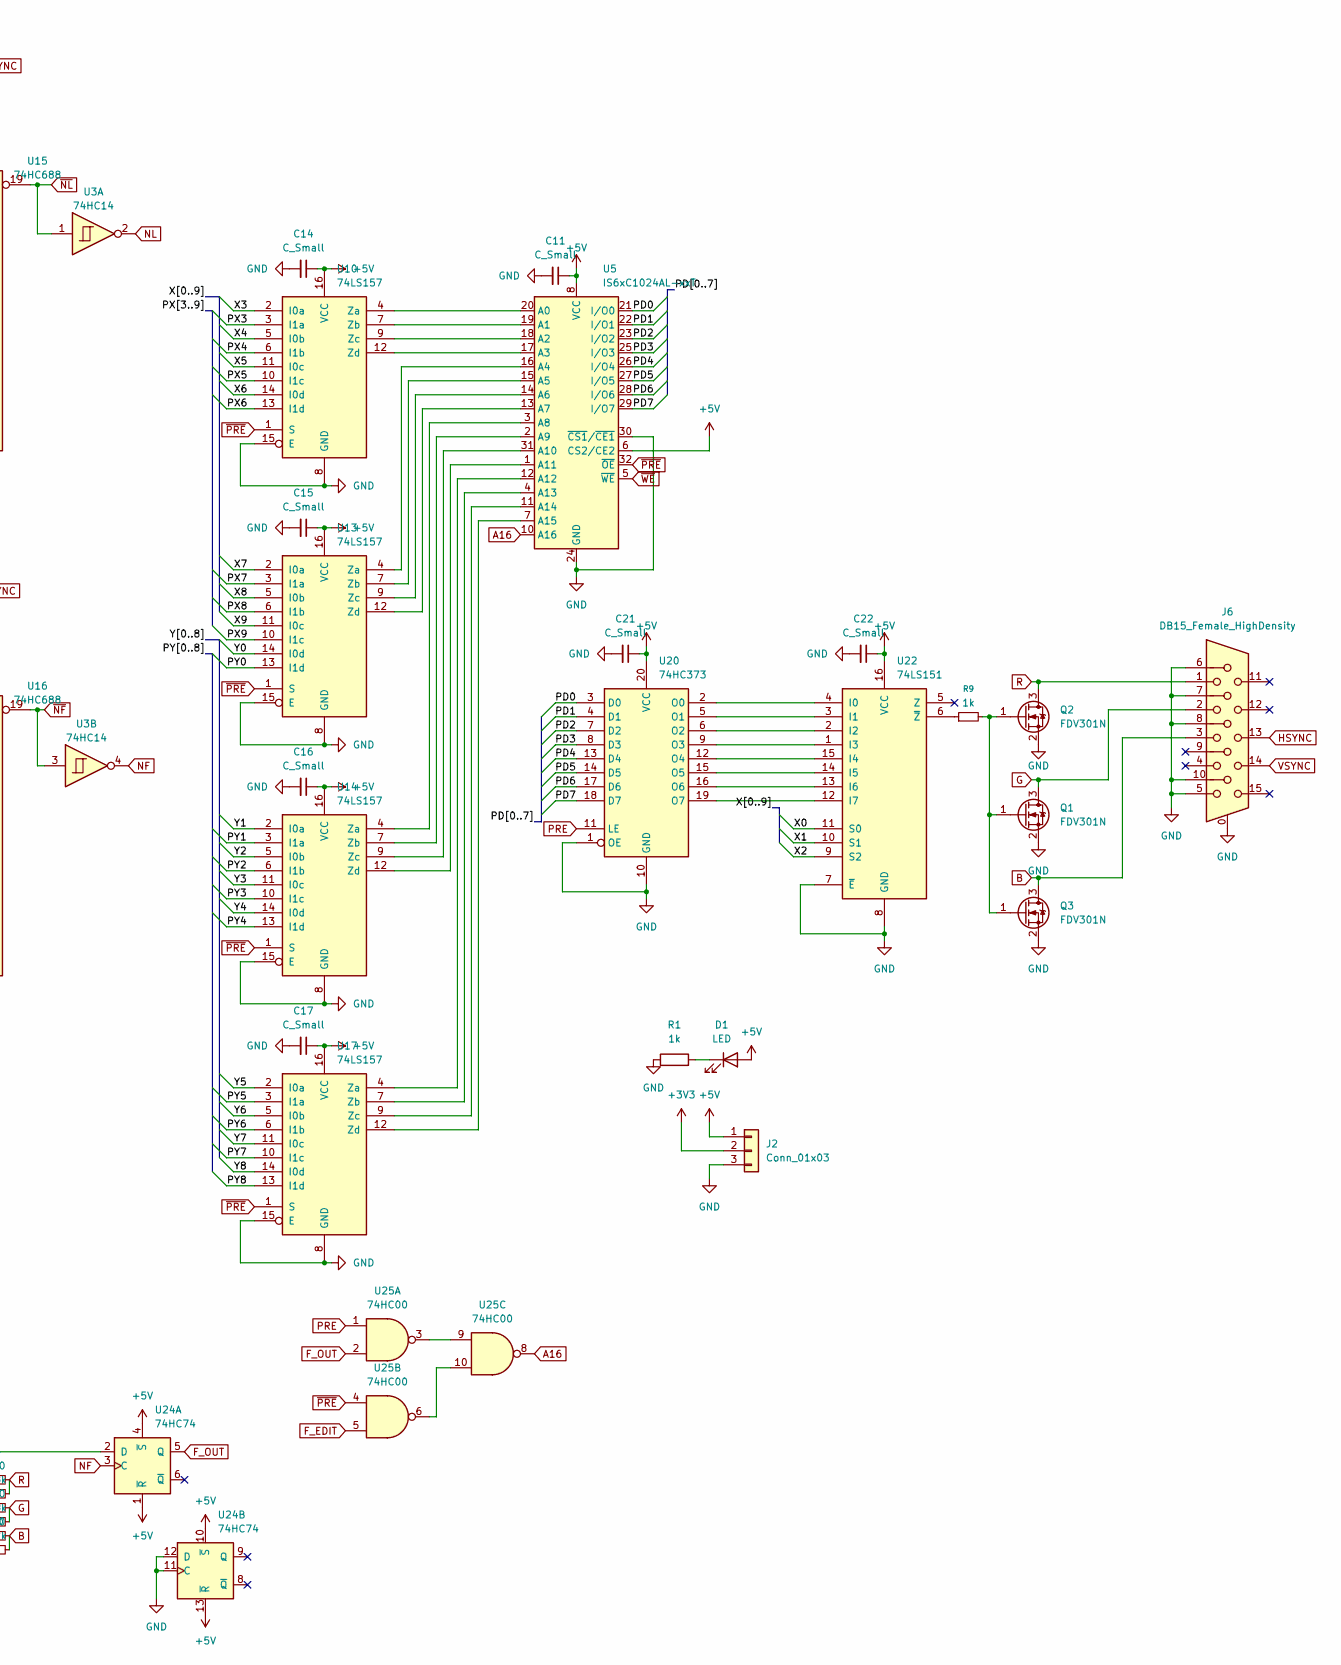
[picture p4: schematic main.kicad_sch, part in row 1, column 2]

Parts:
C1, C2, C3, C4, C5, C6, C7, C8, C9, C10, C11, C12, C13, C14, C15, C16, C17, C18, C19, C20, C21, C22, C23, C24, C25: C_Small; C_Disc_D3.0mm_W2.0mm_P2.50mm
D1: LED; LED_D3.0mm
J1: Conn_02x10_Counter_Clockwise; AliExpress_20Edge
J2: Conn_01x03; PinSocket_1x03_P2.54mm_Vertical
J6: DB15_Female_HighDensity; DSUB-15-HD_Socket_Horizontal_P2.29x1.90mm_EdgePinOffset3.03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
Q1, Q2, Q3: FDV301N; SOT-23-3
R1, R9: 1k; R_Axial_DIN0204_L3.6mm_D1.6mm_P5.08mm_Horizontal
R4, R6, R8: 800; R_Axial_DIN0204_L3.6mm_D1.6mm_P5.08mm_Horizontal
R5, R7, R10: 1.2k; R_Axial_DIN0204_L3.6mm_D1.6mm_P5.08mm_Horizontal
U1, U4: 74HC4040; DIP-16_W7.62mm_Socket
U2, U24: 74HC74; DIP-14_W7.62mm_Socket
U3: 74HC14; DIP-14_W7.62mm_Socket
U5: IS6xC1024AL-xxT; TSOP-I-32_18.4x8mm_P0.5mm
U6: 74HC238; DIP-16_W7.62mm_Socket
U7, U8, U11, U12, U15, U16: 74HC688; DIP-20_W7.62mm_Socket
U9, U18, U19, U20, U23: 74HC373; DIP-20_W7.62mm_Socket
U10, U13, U14, U17: 74LS157; DIP-16_W7.62mm_Socket
U21: 74LS20; DIP-14_W7.62mm_Socket
U22: 74LS151; DIP-16_W7.62mm_Socket
U25: 74HC00; DIP-14_W7.62mm_Socket
Y2: CXO_DIP8; Oscillator_DIP-8

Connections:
+3V3: J1.19, J2.2
+5V: C1.2, C2.1, C3.1, C4.1, C5.1, C6.1, C7.1, C8.1, C9.1, C10.2, C11.1, C12.2, C13.2, C14.1, C15.1, C16.1, C17.1, C18.2, C19.2, C20.1, C21.1, C22.1, C23.2, C24.1, C25.1, D1.2 (A), J1.18, J1.20, J2.1, U1.16 (VCC), U2.14 (VCC), U3.14 (VCC), U4.16 (VCC), U5.6 (CS2/CE2), U5.8 (VCC), U6.16 (VCC), U7.3 (R0), U7.9 (R3), U7.14 (R5), U7.20 (VCC), U8.3 (R0), U8.7 (R2), U8.12 (R4), U8.14 (R5), U8.16 (R6), U8.18 (R7), U8.20 (VCC), U9.20 (VCC), U10.16 (VCC), U11.3 (R0), U11.5 (R1), U11.7 (R2), U11.9 (R3), U11.14 (R5), U11.20 (VCC), U12.5 (R1), U12.7 (R2), U12.12 (R4), U12.14 (R5), U12.16 (R6), U12.18 (R7), U12.20 (VCC), U13.16 (VCC), U14.16 (VCC), U15.5 (R1), U15.12 (R4), U15.14 (R5), U15.20 (VCC), U16.3 (R0), U16.7 (R2), U16.9 (R3), U16.18 (R7), U16.20 (VCC), U17.16 (VCC), U18.20 (VCC), U19.20 (VCC), U20.20 (VCC), U21.12, U21.13, U21.14 (VCC), U22.16 (VCC), U23.20 (VCC), U24.1 (~R), U24.4 (~S), U24.10 (~S), U24.13 (~R), U24.14 (VCC), U25.14 (VCC), Y2.8 (Vcc)
/A0: J1.9, U6.1 (A0)
/A1: J1.10, U6.2 (A1)
/D0: J1.1, U9.3 (D0), U18.3 (D0), U19.3 (D0), U23.3 (D0)
/D1: J1.2, U9.4 (D1), U18.4 (D1), U19.4 (D1), U23.4 (D1)
/D2: J1.3, U9.7 (D2), U18.7 (D2), U19.7 (D2), U23.7 (D2)
/D3: J1.4, U9.8 (D3), U18.8 (D3), U19.8 (D3), U23.8 (D3)
/D4: J1.5, U9.13 (D4), U18.13 (D4), U19.13 (D4), U23.13 (D4)
/D5: J1.6, U9.14 (D5), U18.14 (D5), U19.14 (D5), U23.14 (D5)
/D6: J1.7, U9.17 (D6), U18.17 (D6), U19.17 (D6), U23.17 (D6)
/D7: J1.8, U9.18 (D7), U18.18 (D7), U19.18 (D7), U23.18 (D7)
/PD0: U5.21 (I/O0), U19.2 (O0), U20.3 (D0)
/PD1: U5.22 (I/O1), U19.5 (O1), U20.4 (D1)
/PD2: U5.23 (I/O2), U19.6 (O2), U20.7 (D2)
/PD3: U5.25 (I/O3), U19.9 (O3), U20.8 (D3)
/PD4: U5.26 (I/O4), U19.12 (O4), U20.13 (D4)
/PD5: U5.27 (I/O5), U19.15 (O5), U20.14 (D5)
/PD6: U5.28 (I/O6), U19.16 (O6), U20.17 (D6)
/PD7: U5.29 (I/O7), U19.19 (O7), U20.18 (D7)
/PX3: U9.2 (O0), U10.3 (I1a)
/PX4: U9.5 (O1), U10.6 (I1b)
/PX5: U9.6 (O2), U10.10 (I1c)
/PX6: U9.9 (O3), U10.13 (I1d)
/PX7: U9.12 (O4), U13.3 (I1a)
/PX8: U9.15 (O5), U13.6 (I1b)
/PX9: U9.16 (O6), U13.10 (I1c)
/PY0: U9.19 (O7), U13.13 (I1d)
/PY1: U14.3 (I1a), U18.2 (O0)
/PY2: U14.6 (I1b), U18.5 (O1)
/PY3: U14.10 (I1c), U18.6 (O2)
/PY4: U14.13 (I1d), U18.9 (O3)
/PY5: U17.3 (I1a), U18.12 (O4)
/PY6: U17.6 (I1b), U18.15 (O5)
/PY7: U17.10 (I1c), U18.16 (O6)
/PY8: U17.13 (I1d), U18.19 (O7)
/X0: U3.9, U4.9 (Q0), U22.11 (S0)
/X1: U3.11, U4.7 (Q1), U22.10 (S1)
/X2: U4.6 (Q2), U22.9 (S2), U25.12, U25.13
/X3: U4.5 (Q3), U10.2 (I0a)
/X4: U4.3 (Q4), U7.2 (P0), U10.5 (I0b), U11.2 (P0), U15.2 (P0)
/X5: U4.2 (Q5), U7.4 (P1), U10.11 (I0c), U11.4 (P1), U15.4 (P1)
/X6: U4.4 (Q6), U7.6 (P2), U10.14 (I0d), U11.6 (P2), U15.6 (P2)
/X7: U4.13 (Q7), U7.8 (P3), U11.8 (P3), U13.2 (I0a), U15.8 (P3)
/X8: U4.12 (Q8), U7.11 (P4), U11.11 (P4), U13.5 (I0b), U15.11 (P4)
/X9: U4.14 (Q9), U7.13 (P5), U11.13 (P5), U13.11 (I0c), U15.13 (P5)
/Y0: U1.9 (Q0), U13.14 (I0d), U16.2 (P0)
/Y1: U1.7 (Q1), U8.2 (P0), U12.2 (P0), U14.2 (I0a), U16.4 (P1)
/Y2: U1.6 (Q2), U8.4 (P1), U12.4 (P1), U14.5 (I0b), U16.6 (P2)
/Y3: U1.5 (Q3), U8.6 (P2), U12.6 (P2), U14.11 (I0c), U16.8 (P3)
/Y4: U1.3 (Q4), U8.8 (P3), U12.8 (P3), U14.14 (I0d), U16.11 (P4)
/Y5: U1.2 (Q5), U8.11 (P4), U12.11 (P4), U16.13 (P5), U17.2 (I0a)
/Y6: U1.4 (Q6), U8.13 (P5), U12.13 (P5), U16.15 (P6), U17.5 (I0b)
/Y7: U1.13 (Q7), U8.15 (P6), U12.15 (P6), U17.11 (I0c)
/Y8: U1.12 (Q8), U8.17 (P7), U12.17 (P7), U17.14 (I0d)
/Y9: U1.14 (Q9), U16.17 (P7)
A16: U5.10 (A16), U25.8
B: J6.3, Q3.3 (D), R8.2, R10.2
C_W: U6.12 (Y3), U23.11 (LE)
D_W: U6.13 (Y2), U19.11 (LE)
F_EDIT: U23.5 (O1), U25.5
F_OUT: U24.5 (Q), U25.2
G: J6.2, Q1.3 (D), R6.2, R7.2
GND: C1.1, C2.2, C3.2, C4.2, C5.2, C6.2, C7.2, C8.2, C9.2, C10.1, C11.2, C12.1, C13.1, C14.2, C15.2, C16.2, C17.2, C18.1, C19.1, C20.2, C21.2, C22.2, C23.1, C24.2, C25.2, J1.17, J2.3, J6.0, J6.5, J6.6, J6.7, J6.8, J6.10, Q1.2 (S), Q2.2 (S), Q3.2 (S), R1.1, U1.8 (GND), U2.2 (D), U2.3 (C), U2.7 (GND), U2.11 (C), U2.12 (D), U3.7 (GND), U4.8 (GND), U5.24 (GND), U5.30 (~CS1/~CE1), U6.3 (A2), U6.8 (GND), U7.1 (G), U7.5 (R1), U7.7 (R2), U7.10 (GND), U7.12 (R4), U7.15 (P6), U7.16 (R6), U7.17 (P7), U7.18 (R7), U8.1 (G), U8.5 (R1), U8.9 (R3), U8.10 (GND), U9.1 (OE), U9.10 (GND), U10.8 (GND), U10.15 (E), U11.1 (G), U11.10 (GND), U11.12 (R4), U11.15 (P6), U11.16 (R6), U11.17 (P7), U11.18 (R7), U12.1 (G), U12.3 (R0), U12.9 (R3), U12.10 (GND), U13.8 (GND), U13.15 (E), U14.8 (GND), U14.15 (E), U15.1 (G), U15.3 (R0), U15.7 (R2), U15.9 (R3), U15.10 (GND), U15.15 (P6), U15.16 (R6), U15.17 (P7), U15.18 (R7), U16.1 (G), U16.5 (R1), U16.10 (GND), U16.12 (R4), U16.14 (R5), U16.16 (R6), U17.8 (GND), U17.15 (E), U18.1 (OE), U18.10 (GND), U19.10 (GND), U20.1 (OE), U20.10 (GND), U21.7 (GND), U22.7 (~E), U22.8 (GND), U23.1 (OE), U23.10 (GND), U24.7 (GND), U24.11 (C), U24.12 (D), U25.7 (GND), Y2.4 (GND)
HSYNC: J6.13, U2.6 (~Q)
NF: U1.11 (MR), U3.4, U24.3 (C)
NL: U3.2, U4.11 (MR)
unnamed: D1.1 (K), R1.2
unnamed: Q1.1 (G), Q2.1 (G), Q3.1 (G), R9.2
unnamed: U2.4 (~S), U7.19 (P=R)
unnamed: U2.10 (~S), U8.19 (P=R)
unnamed: U5.20 (A0), U10.4 (Za)
unnamed: U5.19 (A1), U10.7 (Zb)
unnamed: U5.18 (A2), U10.9 (Zc)
unnamed: U5.17 (A3), U10.12 (Zd)
unnamed: U2.1 (~R), U11.19 (P=R)
unnamed: U2.13 (~R), U12.19 (P=R)
unnamed: U5.16 (A4), U13.4 (Za)
unnamed: U5.15 (A5), U13.7 (Zb)
unnamed: U5.14 (A6), U13.9 (Zc)
unnamed: U5.13 (A7), U13.12 (Zd)
unnamed: U5.3 (A8), U14.4 (Za)
unnamed: U5.2 (A9), U14.7 (Zb)
unnamed: U5.31 (A10), U14.9 (Zc)
unnamed: U5.1 (A11), U14.12 (Zd)
unnamed: U5.12 (A12), U17.4 (Za)
unnamed: U5.4 (A13), U17.7 (Zb)
unnamed: U5.11 (A14), U17.9 (Zc)
unnamed: U5.7 (A15), U17.12 (Zd)
unnamed: U20.2 (O0), U22.4 (I0)
unnamed: U20.5 (O1), U22.3 (I1)
unnamed: U20.6 (O2), U22.2 (I2)
unnamed: U20.9 (O3), U22.1 (I3)
unnamed: U20.12 (O4), U22.15 (I4)
unnamed: U20.15 (O5), U22.14 (I5)
unnamed: U20.16 (O6), U22.13 (I6)
unnamed: U20.19 (O7), U22.12 (I7)
unnamed: U3.8, U21.1
unnamed: U3.10, U21.2
unnamed: U21.4, U25.11
unnamed: R9.1, U22.6 (~Z)
unnamed: U23.2 (O0), U24.2 (D)
unnamed: R4.1, U23.6 (O2)
unnamed: R5.1, U23.9 (O3)
unnamed: R6.1, U23.12 (O4)
unnamed: R7.1, U23.15 (O5)
unnamed: R8.1, U23.16 (O6)
unnamed: R10.1, U23.19 (O7)
unnamed: U25.3, U25.9
unnamed: U25.6, U25.10
PHI2: J1.16, U6.6 (E3)
PRE: U3.6, U19.1 (OE), U20.11 (LE), U25.1
R: J6.1, Q2.3 (D), R4.2, R5.2
R/~W: J1.15, U6.5 (~E2)
VCLK: U3.13, U4.10 (~CP), U21.10, Y2.5 (OUT)
VSYNC: J6.14, U2.8 (~Q)
X_W: U6.15 (Y0), U9.11 (LE)
Y_W: U6.14 (Y1), U18.11 (LE)
~D2_SEL: J1.13, U6.4 (~E1)
~NF: U3.3, U16.19 (P=R)
~NL: U1.10 (~CP), U3.1, U15.19 (P=R)
~PRE: U3.5, U5.32 (~OE), U10.1 (S), U13.1 (S), U14.1 (S), U17.1 (S), U21.6, U21.9, U25.4
~VCLK: U3.12, U21.5
~WE: U5.5 (~WE), U21.8

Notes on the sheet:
Goes to LE on all registers

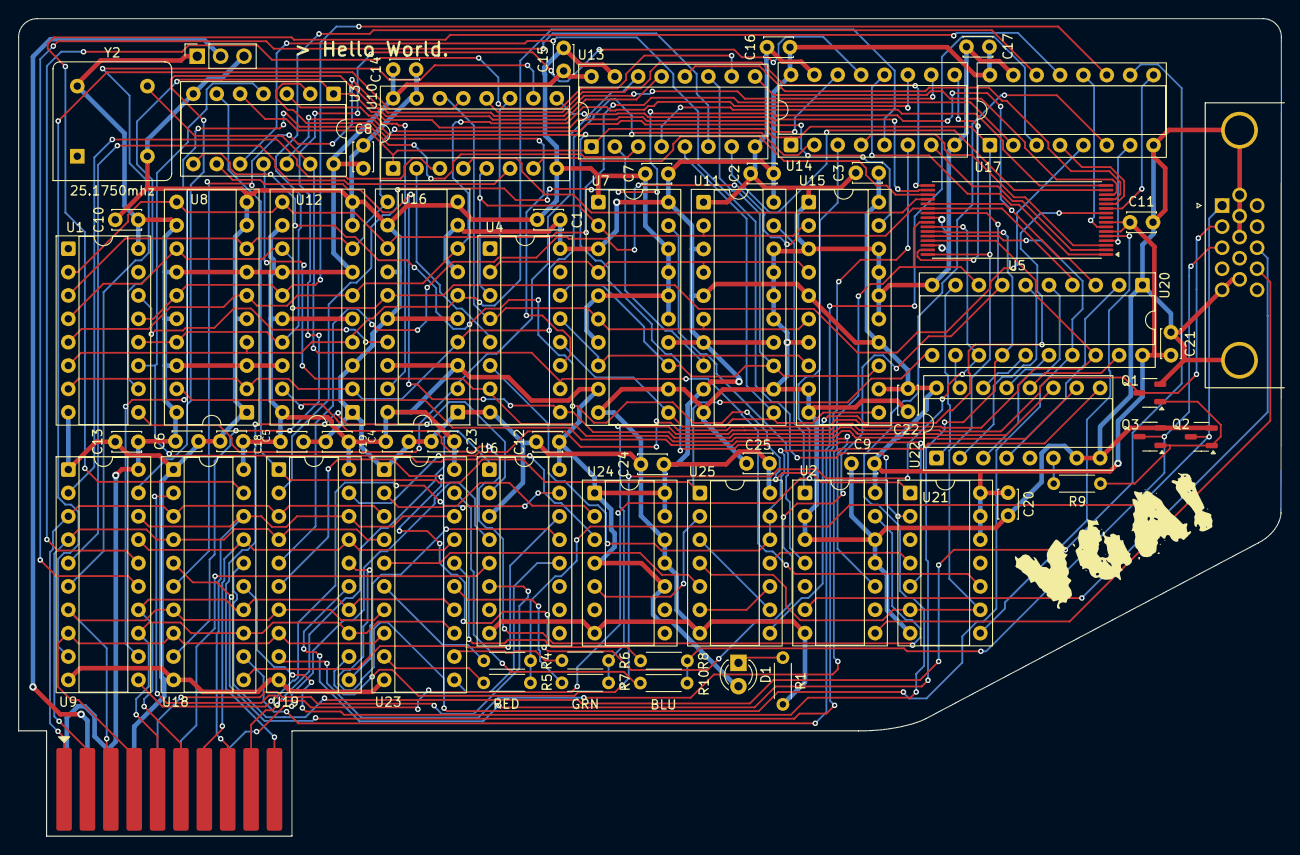
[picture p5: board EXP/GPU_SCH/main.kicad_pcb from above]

Board: 2 copper layers, 137.2 x 88.8 mm, 66 parts (0 on the bottom side), 124 nets.

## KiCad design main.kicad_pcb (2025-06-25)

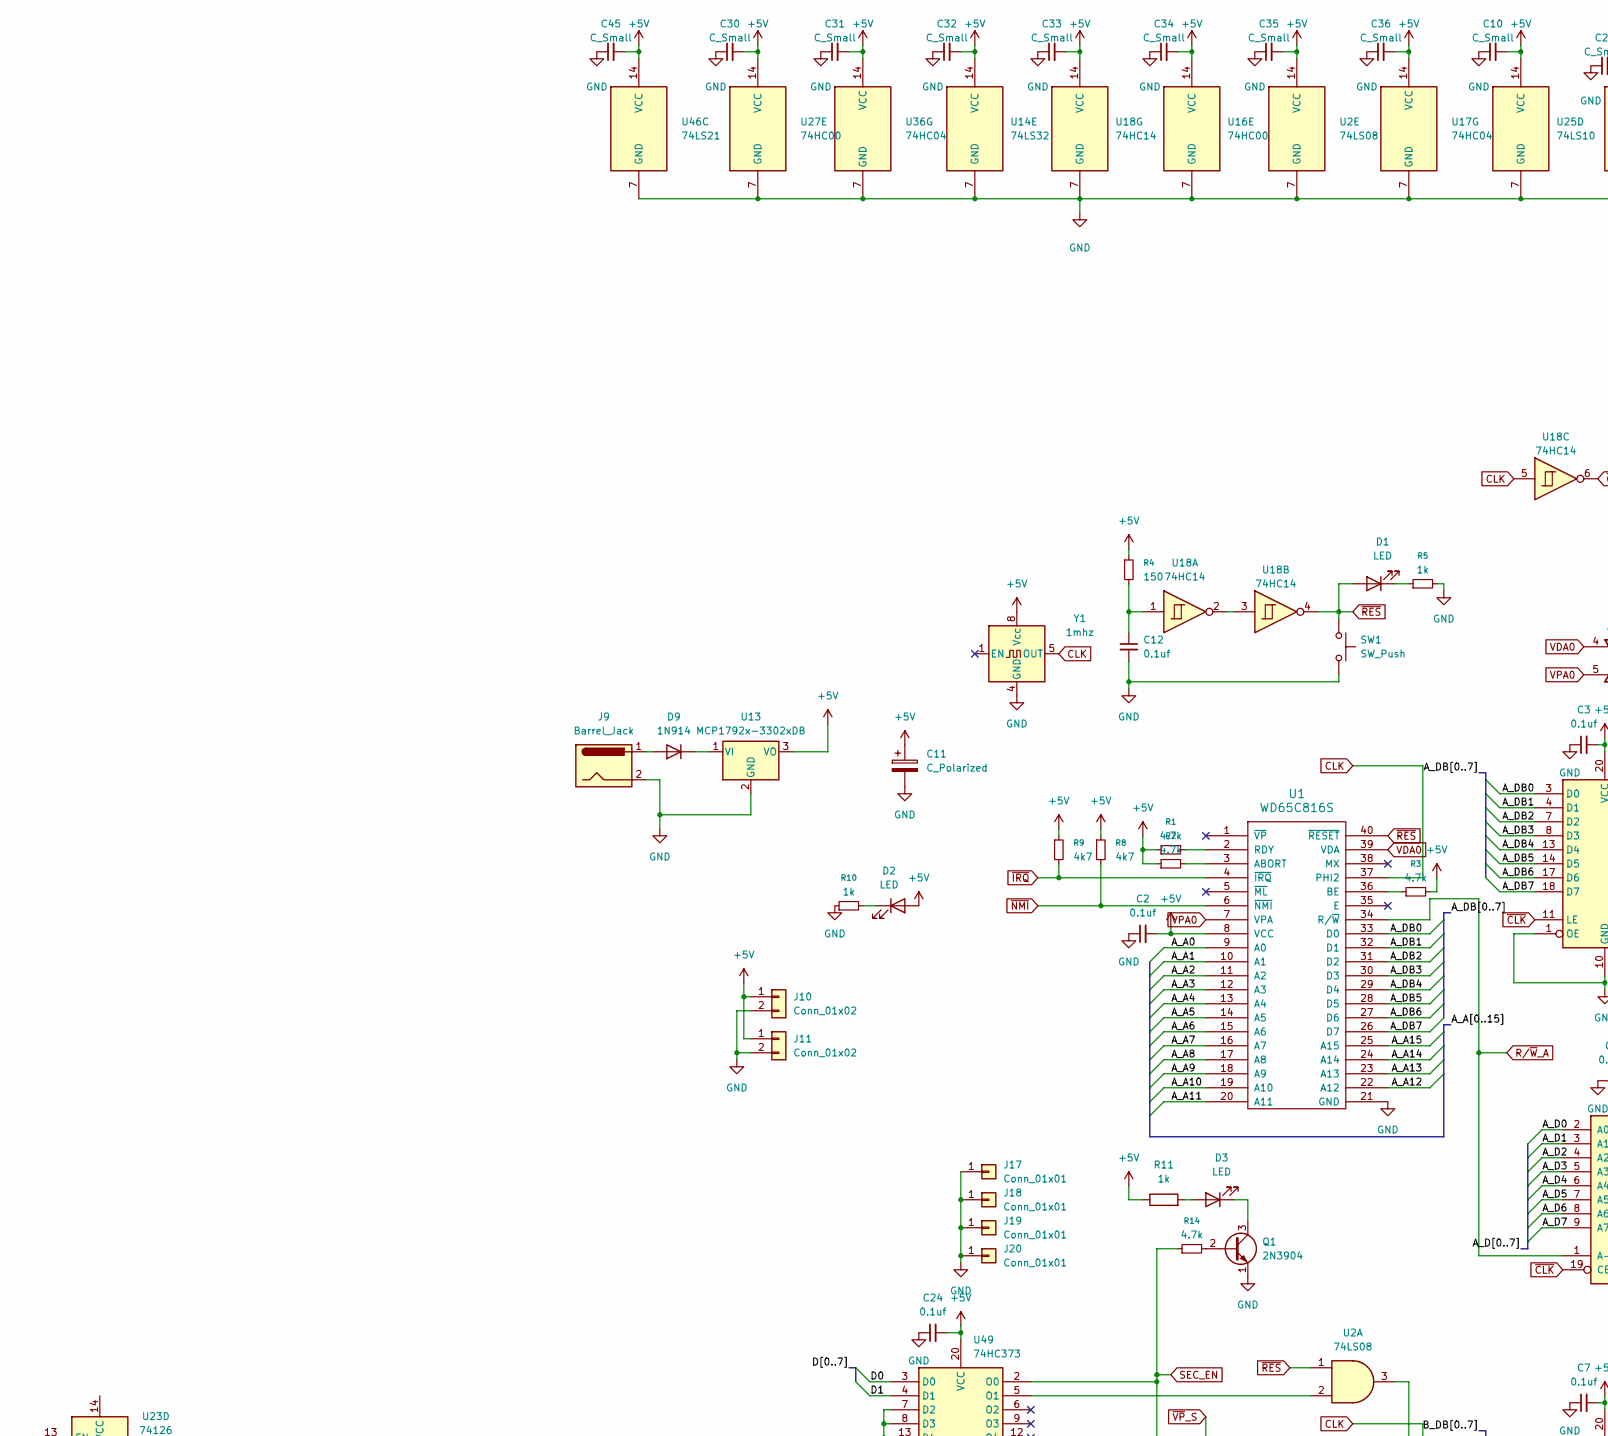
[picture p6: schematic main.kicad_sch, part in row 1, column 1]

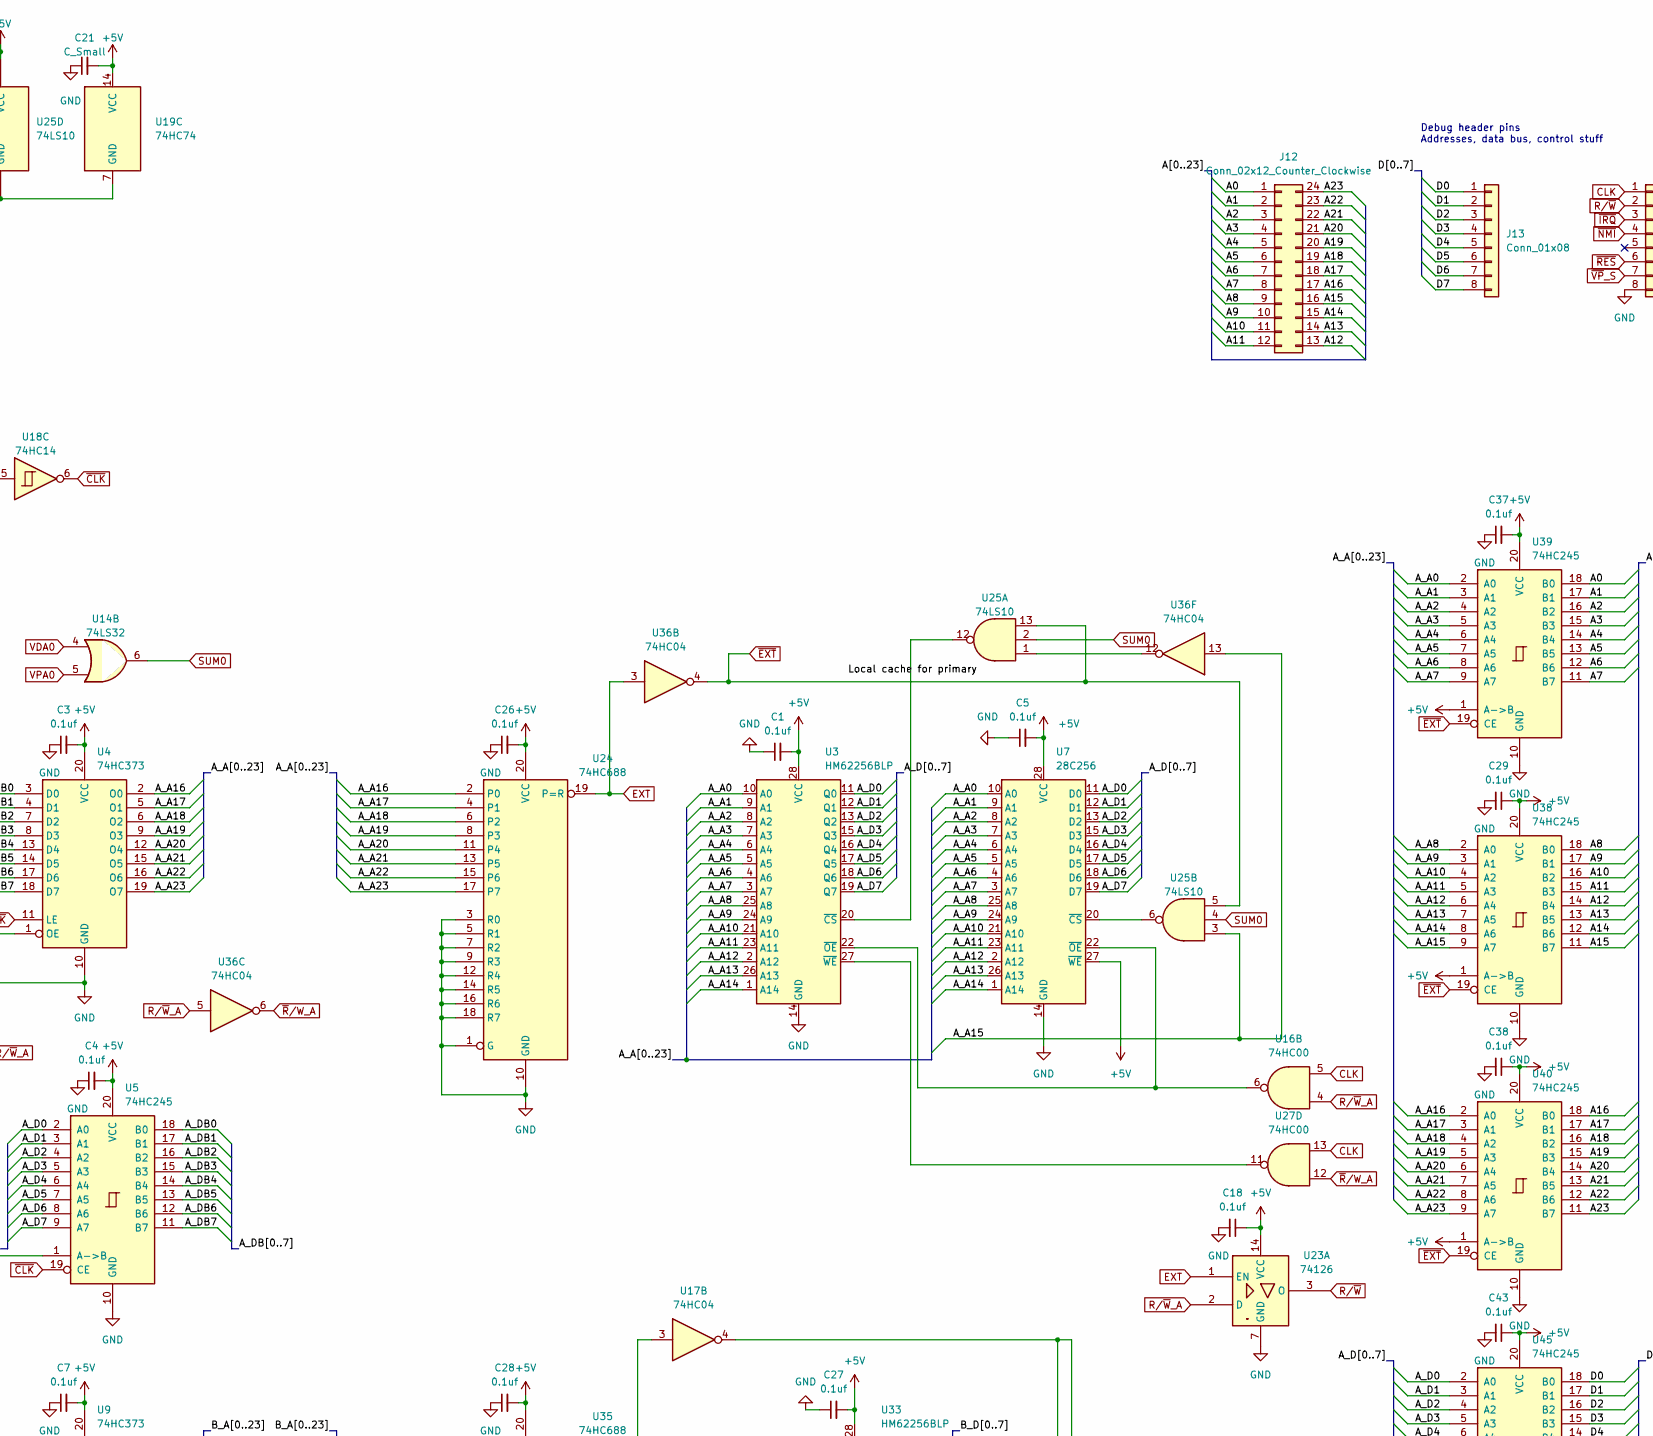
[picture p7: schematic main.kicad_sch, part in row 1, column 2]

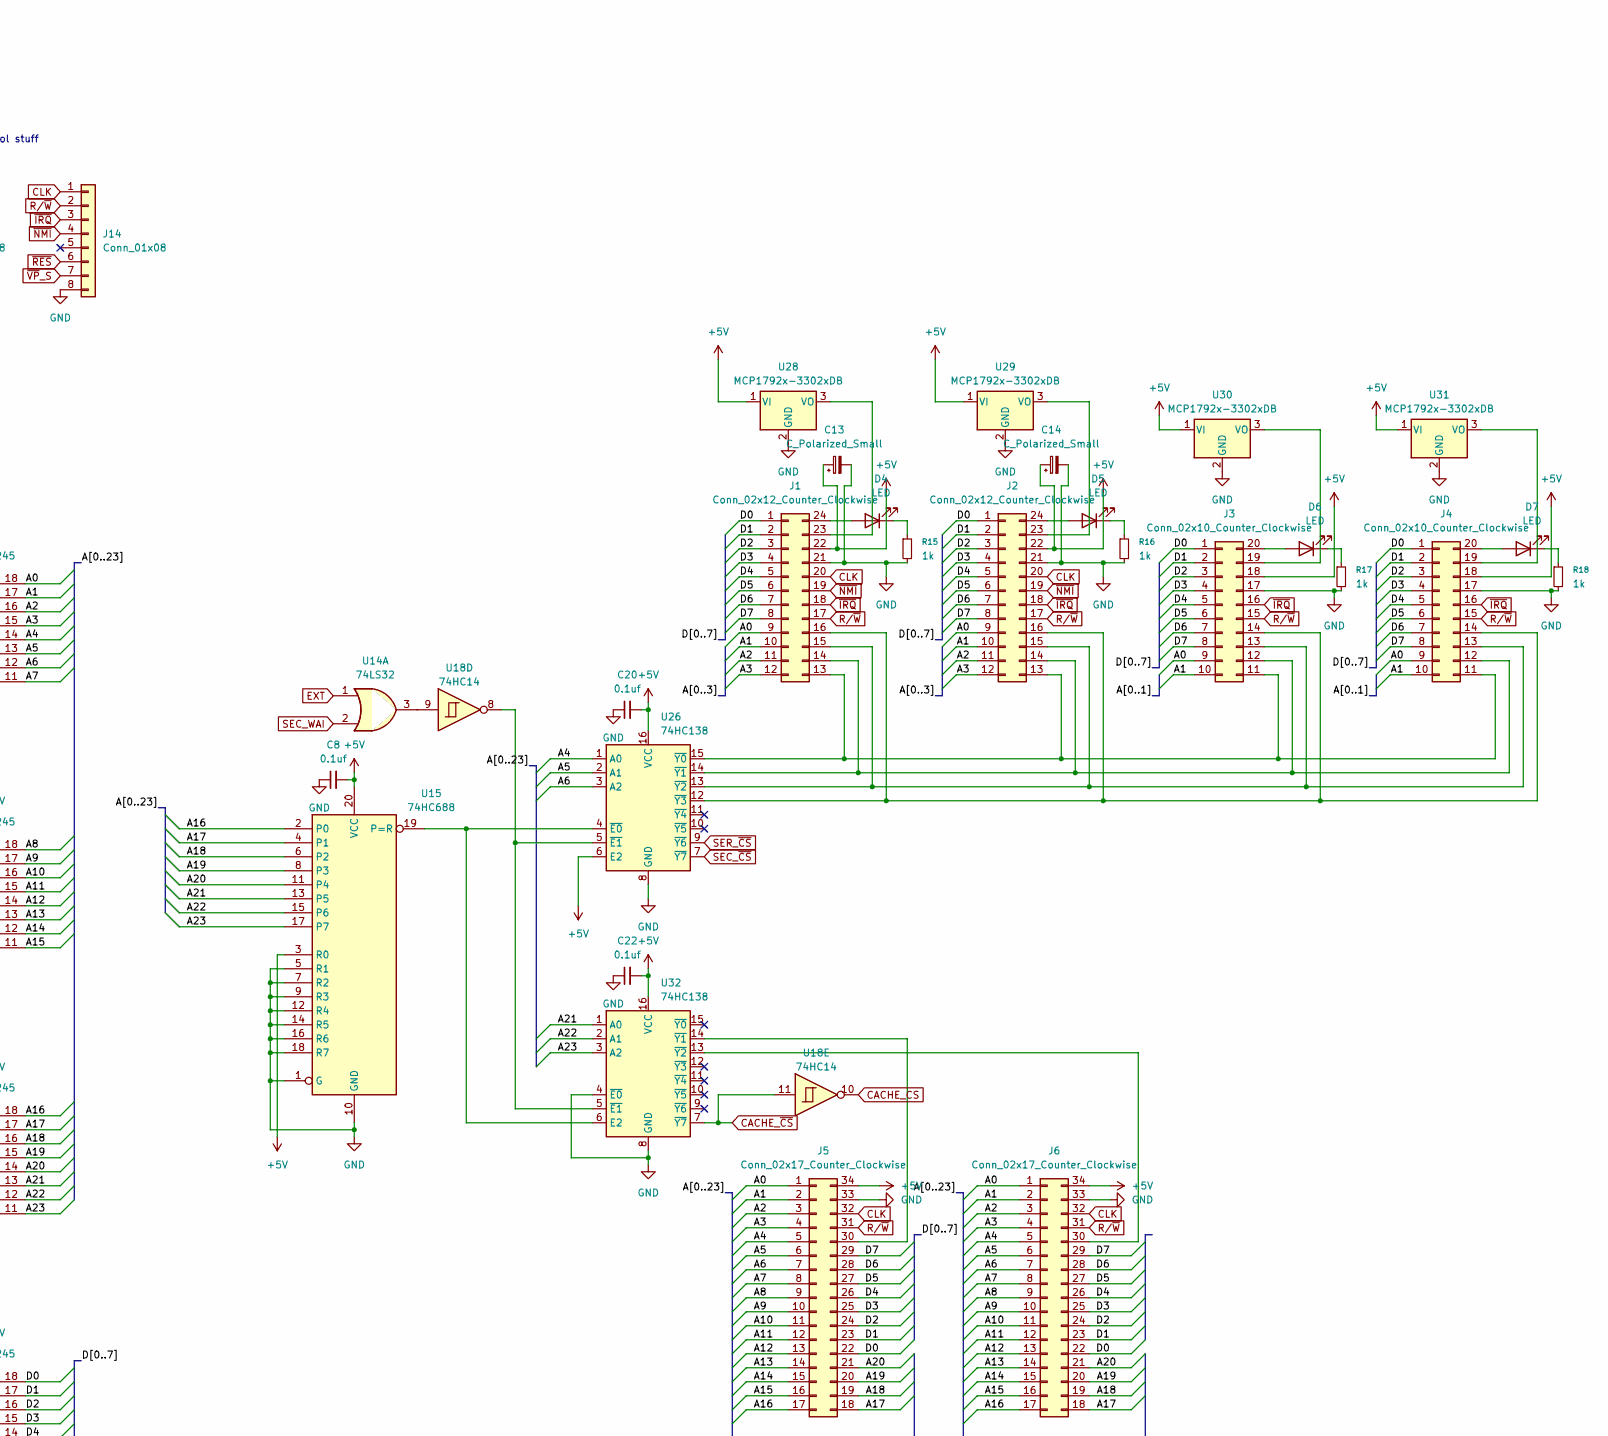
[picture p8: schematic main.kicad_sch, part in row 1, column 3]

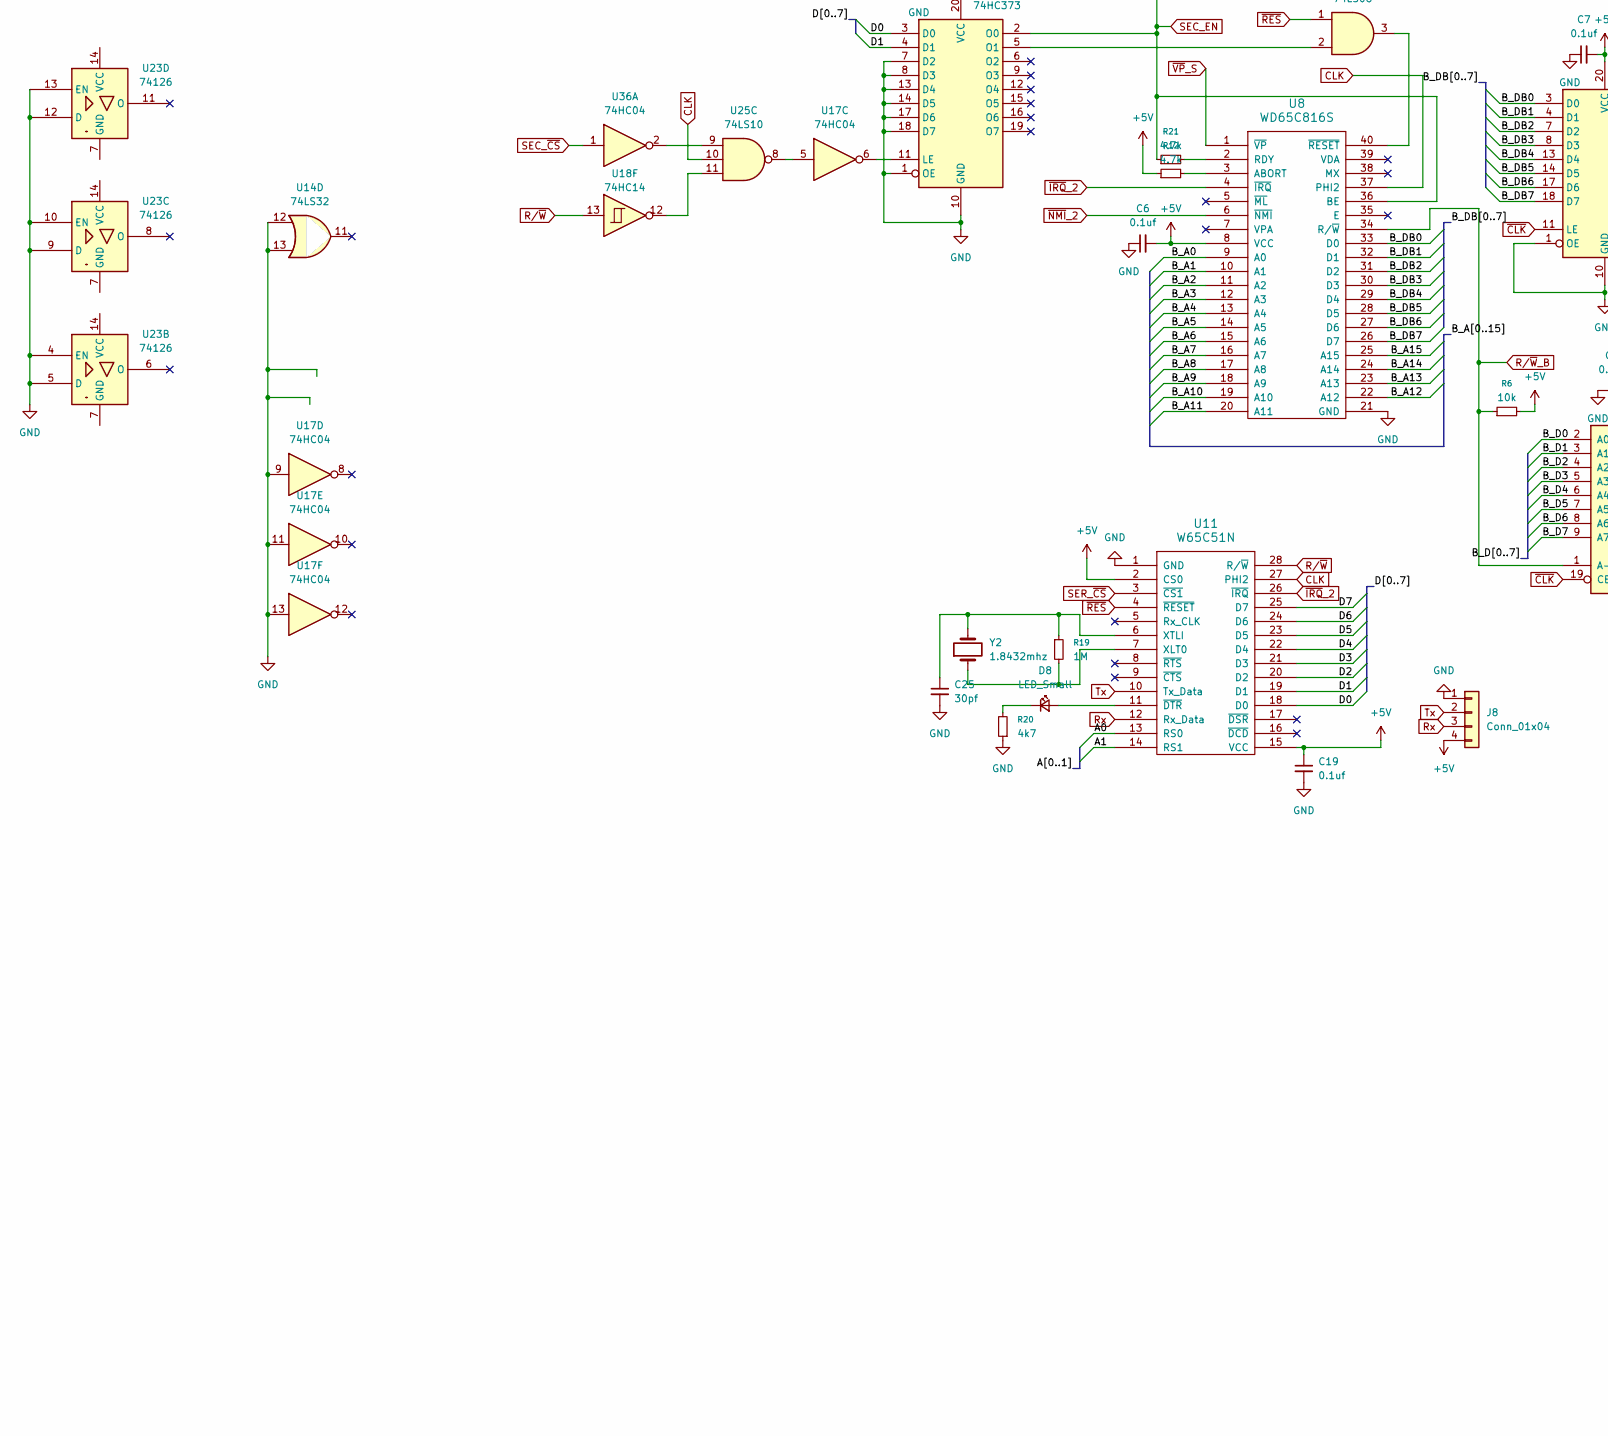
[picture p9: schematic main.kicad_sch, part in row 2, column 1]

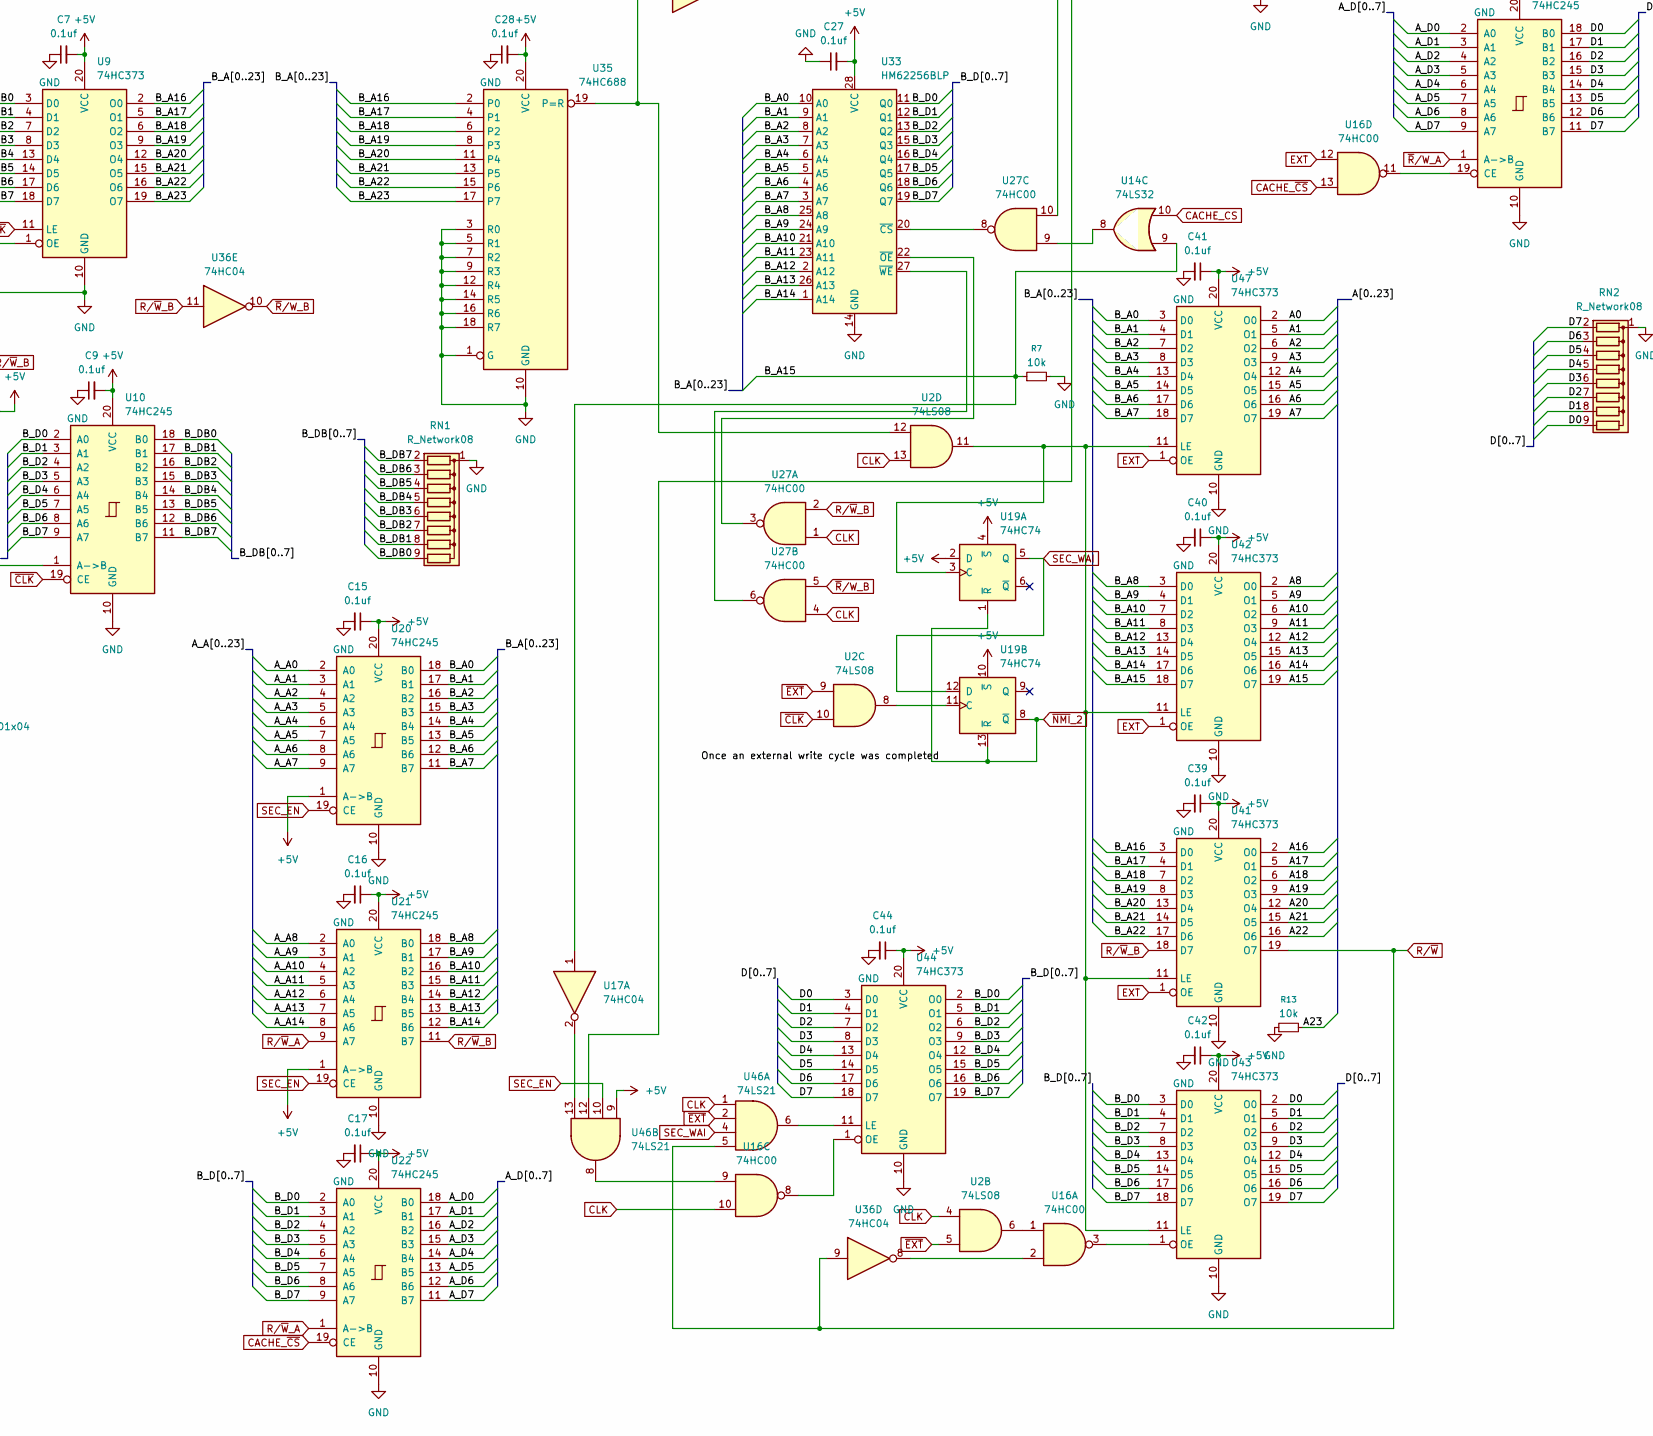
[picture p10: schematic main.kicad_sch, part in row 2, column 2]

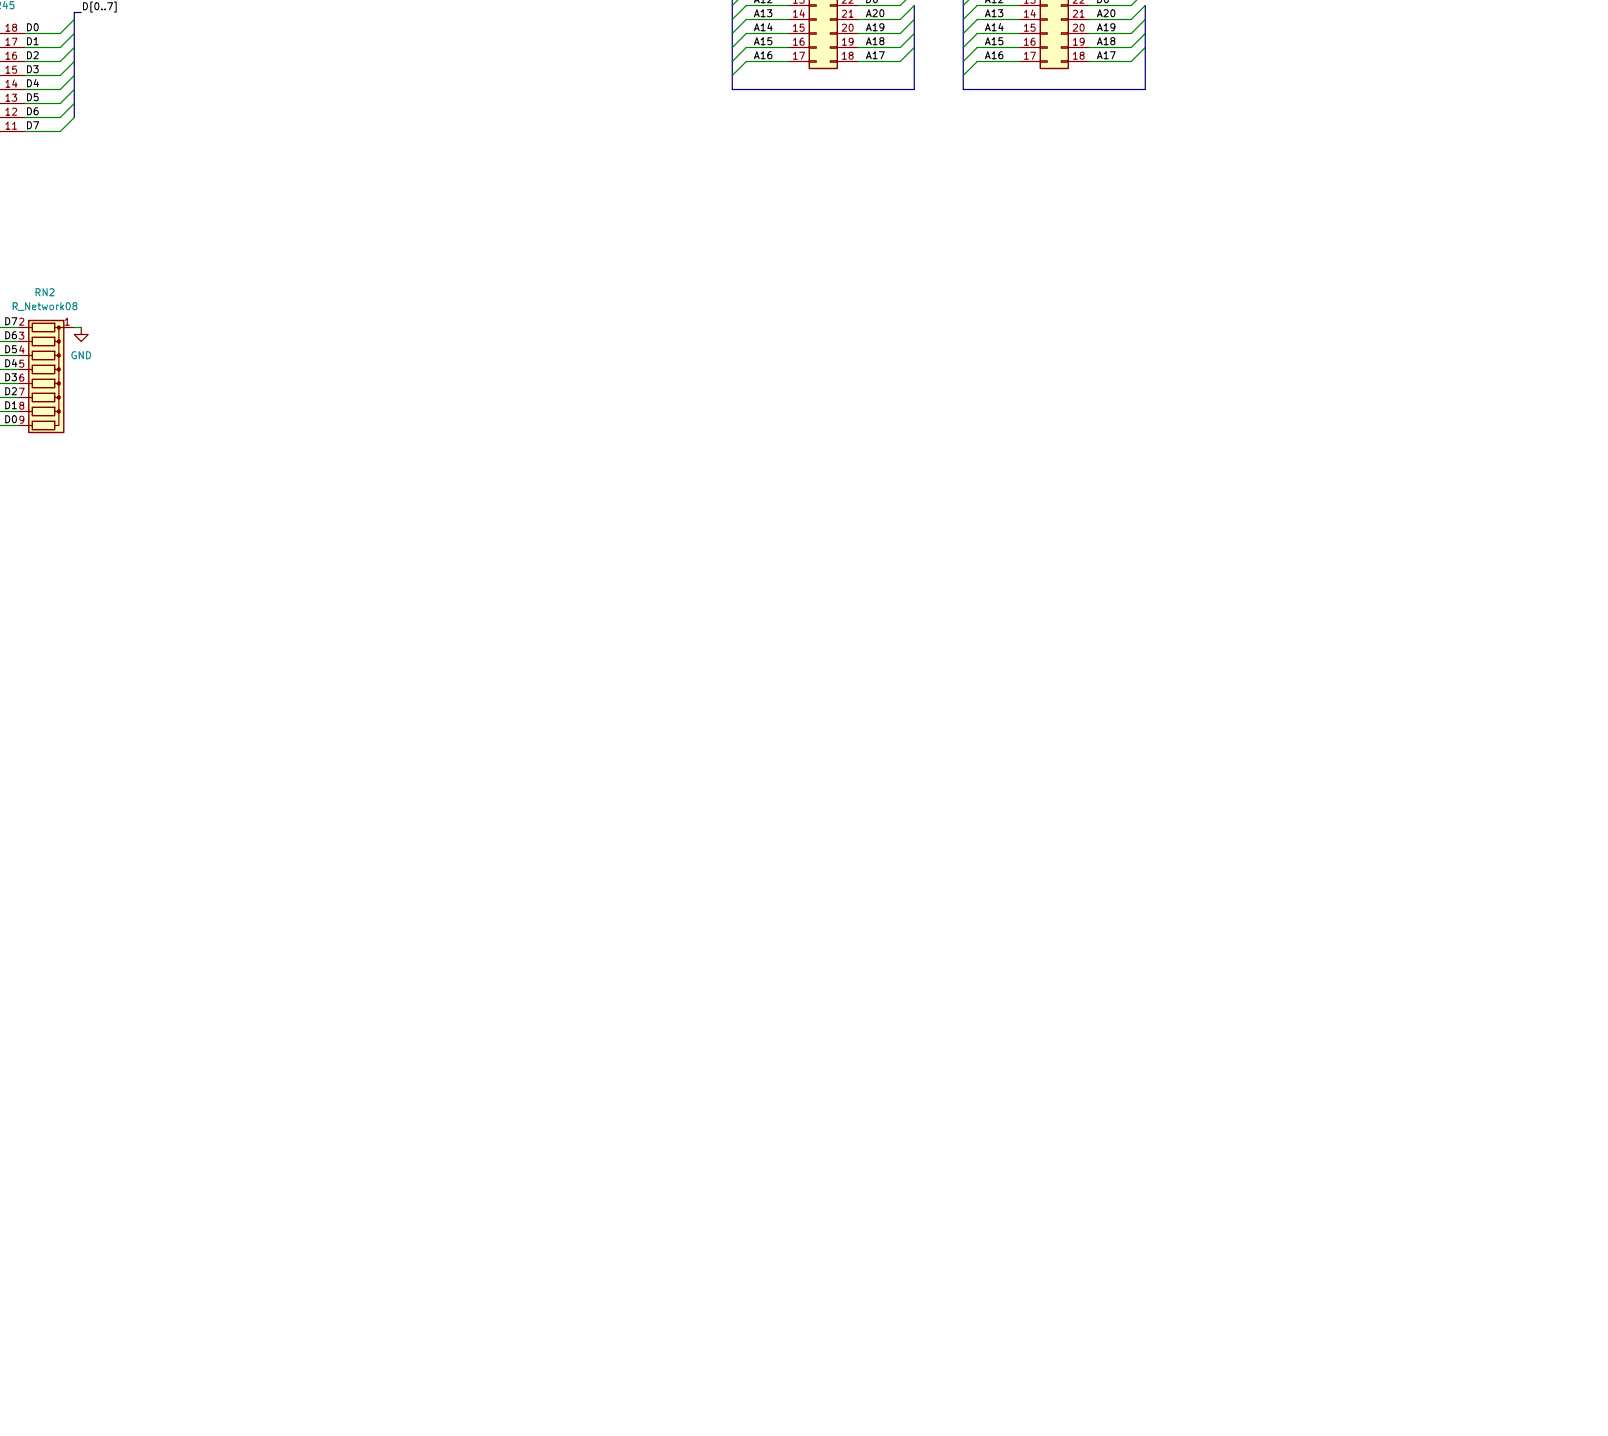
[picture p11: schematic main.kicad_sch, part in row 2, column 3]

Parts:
C1, C2, C3, C4, C5, C6, C7, C8, C9, C12, C15, C16, C17, C18, C19, C20, C22, C24, C26, C27, C28, C29, C37, C38, C39, C40, C41, C42, C43, C44: 0.1uf; C_1206_3216Metric
C10, C21, C30, C31, C32, C33, C34, C35, C36, C45: C_Small; C_1206_3216Metric
C11: C_Polarized; CP_Radial_D10.0mm_P3.50mm
C13, C14: C_Polarized_Small; CP_Radial_D5.0mm_P2.00mm
C25: 30pf; C_Disc_D3.0mm_W2.0mm_P2.50mm
D1, D2, D3: LED; LED_D3.0mm
D4, D5, D6, D7: LED; LED_1206_3216Metric
D8: LED_Small; LED_1206_3216Metric_Pad1.42x1.75mm_HandSolder
D9: 1N914; D_1206_3216Metric_Pad1.42x1.75mm_HandSolder
J1, J2: Conn_02x12_Counter_Clockwise; AliExpress_24
J3, J4: Conn_02x10_Counter_Clockwise; AliExpress_20
J5, J6: Conn_02x17_Counter_Clockwise; AliExpress_36
J8: Conn_01x04; PinSocket_1x04_P2.54mm_Vertical
J9: Barrel_Jack; BarrelJack_Horizontal
J10, J11: Conn_01x02; PinHeader_1x02_P2.54mm_Vertical
J12: Conn_02x12_Counter_Clockwise; PinSocket_2x12_P2.54mm_Vertical
J13, J14: Conn_01x08; PinSocket_1x08_P2.54mm_Vertical
J17, J18, J19, J20: Conn_01x01; MountingHole_3mm_Pad
Q1: 2N3904; TO-92_Inline
R1, R2, R3, R12, R14, R21: 4.7k; R_1206_3216Metric_Pad1.30x1.75mm_HandSolder
R4: 150; R_Axial_DIN0204_L3.6mm_D1.6mm_P7.62mm_Horizontal
R5, R10, R11, R15, R16, R17, R18: 1k; R_1206_3216Metric_Pad1.30x1.75mm_HandSolder
R6, R7, R13: 10k; R_1206_3216Metric_Pad1.30x1.75mm_HandSolder
R8, R9, R20: 4k7; R_1206_3216Metric_Pad1.30x1.75mm_HandSolder
R19: 1M; R_Axial_DIN0207_L6.3mm_D2.5mm_P7.62mm_Horizontal
RN1, RN2: R_Network08; R_Array_SIP9
SW1: SW_Push; SW_PUSH_6mm
U1, U8: WD65C816S; DIP-40_W15.24mm_Socket
U2: 74LS08; DIP-14_W7.62mm_Socket
U3, U33: HM62256BLP; DIP-28_W15.24mm_Socket
U4, U9, U41, U42, U43, U44, U47, U49: 74HC373; DIP-20_W7.62mm_Socket
U5, U10, U20, U21, U22, U38, U39, U40, U45: 74HC245; DIP-20_W7.62mm_Socket
U7: 28C256; DIP_Socket-28_W11.9_W12.7_W15.24_W17.78_W18.5_3M_228-1277-0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
U11: W65C51N; DIP-28_W15.24mm_Socket
U13, U28, U29, U30, U31: MCP1792x-3302xDB; SOT-89-3_Handsoldering
U14: 74LS32; DIP-14_W7.62mm_Socket
U15, U24, U35: 74HC688; DIP-20_W7.62mm_Socket
U16, U27: 74HC00; DIP-14_W7.62mm_Socket
U17, U36: 74HC04; DIP-14_W7.62mm_Socket
U18: 74HC14; DIP-14_W7.62mm_Socket
U19: 74HC74; DIP-14_W7.62mm_Socket
U23: 74126; DIP-14_W7.62mm_Socket
U25: 74LS10; DIP-14_W7.62mm_Socket
U26, U32: 74HC138; DIP-16_W7.62mm_Socket
U46: 74LS21; DIP-14_W7.62mm_Socket
Y1: 1mhz; Oscillator_DIP-8
Y2: 1.8432mhz; Crystal_HC52-6mm_Vertical

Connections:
+5V: C1.2, C2.2, C3.2, C4.2, C5.2, C6.2, C7.2, C8.2, C9.2, C10.2, C11.1, C13.1, C14.1, C15.1, C16.1, C17.1, C18.1, C19.1, C20.2, C21.2, C22.2, C24.2, C26.2, C27.2, C28.2, C29.1, C30.2, C31.2, C32.2, C33.2, C34.2, C35.2, C36.2, C37.2, C38.1, C39.1, C40.1, C41.1, C42.1, C43.1, C44.1, C45.2, D2.2 (A), J1.22, J2.22, J3.18, J4.18, J5.34, J6.34, J8.4, J10.1, J11.1, R1.1, R2.1, R3.2, R4.1, R6.2, R8.1, R9.1, R11.1, R12.1, U1.8 (VCC), U2.14 (VCC), U3.28 (VCC), U4.20 (VCC), U5.20 (VCC), U7.27 (~WE), U7.28 (VCC), U8.8 (VCC), U9.20 (VCC), U10.20 (VCC), U11.2 (CS0), U11.15 (VCC), U13.3 (VO), U14.14 (VCC), U15.3 (R0), U15.20 (VCC), U16.14 (VCC), U17.14 (VCC), U18.14 (VCC), U19.2 (D), U19.4 (~S), U19.10 (~S), U19.14 (VCC), U20.1 (A->B), U20.20 (VCC), U21.1 (A->B), U21.20 (VCC), U22.20 (VCC), U23.14 (VCC), U24.20 (VCC), U25.14 (VCC), U26.6 (E2), U26.16 (VCC), U27.14 (VCC), U28.1 (VI), U29.1 (VI), U30.1 (VI), U31.1 (VI), U32.16 (VCC), U33.28 (VCC), U35.20 (VCC), U36.14 (VCC), U38.1 (A->B), U38.20 (VCC), U39.1 (A->B), U39.20 (VCC), U40.1 (A->B), U40.20 (VCC), U41.20 (VCC), U42.20 (VCC), U43.20 (VCC), U44.20 (VCC), U45.20 (VCC), U46.9, U46.14 (VCC), U47.20 (VCC), U49.20 (VCC), Y1.8 (Vcc)
/A0: J1.9, J2.9, J3.9, J4.9, J5.1, J6.1, J12.1, U11.13 (RS0), U39.18 (B0), U47.2 (O0)
/A1: J1.10, J2.10, J3.10, J4.10, J5.2, J6.2, J12.2, U11.14 (RS1), U39.17 (B1), U47.5 (O1)
/A2: J1.11, J2.11, J5.3, J6.3, J12.3, U39.16 (B2), U47.6 (O2)
/A3: J1.12, J2.12, J5.4, J6.4, J12.4, U39.15 (B3), U47.9 (O3)
/A4: J5.5, J6.5, J12.5, U26.1 (A0), U39.14 (B4), U47.12 (O4)
/A5: J5.6, J6.6, J12.6, U26.2 (A1), U39.13 (B5), U47.15 (O5)
/A6: J5.7, J6.7, J12.7, U26.3 (A2), U39.12 (B6), U47.16 (O6)
/A7: J5.8, J6.8, J12.8, U39.11 (B7), U47.19 (O7)
/A8: J5.9, J6.9, J12.9, U38.18 (B0), U42.2 (O0)
/A9: J5.10, J6.10, J12.10, U38.17 (B1), U42.5 (O1)
/A10: J5.11, J6.11, J12.11, U38.16 (B2), U42.6 (O2)
/A11: J5.12, J6.12, J12.12, U38.15 (B3), U42.9 (O3)
/A12: J5.13, J6.13, J12.13, U38.14 (B4), U42.12 (O4)
/A13: J5.14, J6.14, J12.14, U38.13 (B5), U42.15 (O5)
/A14: J5.15, J6.15, J12.15, U38.12 (B6), U42.16 (O6)
/A15: J5.16, J6.16, J12.16, U38.11 (B7), U42.19 (O7)
/A16: J5.17, J6.17, J12.17, U15.2 (P0), U40.18 (B0), U41.2 (O0)
/A17: J5.18, J6.18, J12.18, U15.4 (P1), U40.17 (B1), U41.5 (O1)
/A18: J5.19, J6.19, J12.19, U15.6 (P2), U40.16 (B2), U41.6 (O2)
/A19: J5.20, J6.20, J12.20, U15.8 (P3), U40.15 (B3), U41.9 (O3)
/A20: J5.21, J6.21, J12.21, U15.11 (P4), U40.14 (B4), U41.12 (O4)
/A21: J12.22, U15.13 (P5), U32.1 (A0), U40.13 (B5), U41.15 (O5)
/A22: J12.23, U15.15 (P6), U32.2 (A1), U40.12 (B6), U41.16 (O6)
/A23: J12.24, R13.2, U15.17 (P7), U32.3 (A2), U40.11 (B7)
/A_A0: U1.9 (A0), U3.10 (A0), U7.10 (A0), U20.2 (A0), U39.2 (A0)
/A_A1: U1.10 (A1), U3.9 (A1), U7.9 (A1), U20.3 (A1), U39.3 (A1)
/A_A2: U1.11 (A2), U3.8 (A2), U7.8 (A2), U20.4 (A2), U39.4 (A2)
/A_A3: U1.12 (A3), U3.7 (A3), U7.7 (A3), U20.5 (A3), U39.5 (A3)
/A_A4: U1.13 (A4), U3.6 (A4), U7.6 (A4), U20.6 (A4), U39.6 (A4)
/A_A5: U1.14 (A5), U3.5 (A5), U7.5 (A5), U20.7 (A5), U39.7 (A5)
/A_A6: U1.15 (A6), U3.4 (A6), U7.4 (A6), U20.8 (A6), U39.8 (A6)
/A_A7: U1.16 (A7), U3.3 (A7), U7.3 (A7), U20.9 (A7), U39.9 (A7)
/A_A8: U1.17 (A8), U3.25 (A8), U7.25 (A8), U21.2 (A0), U38.2 (A0)
/A_A9: U1.18 (A9), U3.24 (A9), U7.24 (A9), U21.3 (A1), U38.3 (A1)
/A_A10: U1.19 (A10), U3.21 (A10), U7.21 (A10), U21.4 (A2), U38.4 (A2)
/A_A11: U1.20 (A11), U3.23 (A11), U7.23 (A11), U21.5 (A3), U38.5 (A3)
/A_A12: U1.22 (A12), U3.2 (A12), U7.2 (A12), U21.6 (A4), U38.6 (A4)
/A_A13: U1.23 (A13), U3.26 (A13), U7.26 (A13), U21.7 (A5), U38.7 (A5)
/A_A14: U1.24 (A14), U3.1 (A14), U7.1 (A14), U21.8 (A6), U38.8 (A6)
/A_A15: U1.25 (A15), U25.3, U36.13, U38.9 (A7)
/A_A16: U4.2 (O0), U24.2 (P0), U40.2 (A0)
/A_A17: U4.5 (O1), U24.4 (P1), U40.3 (A1)
/A_A18: U4.6 (O2), U24.6 (P2), U40.4 (A2)
/A_A19: U4.9 (O3), U24.8 (P3), U40.5 (A3)
/A_A20: U4.12 (O4), U24.11 (P4), U40.6 (A4)
/A_A21: U4.15 (O5), U24.13 (P5), U40.7 (A5)
/A_A22: U4.16 (O6), U24.15 (P6), U40.8 (A6)
/A_A23: U4.19 (O7), U24.17 (P7), U40.9 (A7)
/A_D0: U3.11 (Q0), U5.2 (A0), U7.11 (D0), U22.18 (B0), U45.2 (A0)
/A_D1: U3.12 (Q1), U5.3 (A1), U7.12 (D1), U22.17 (B1), U45.3 (A1)
/A_D2: U3.13 (Q2), U5.4 (A2), U7.13 (D2), U22.16 (B2), U45.4 (A2)
/A_D3: U3.15 (Q3), U5.5 (A3), U7.15 (D3), U22.15 (B3), U45.5 (A3)
/A_D4: U3.16 (Q4), U5.6 (A4), U7.16 (D4), U22.14 (B4), U45.6 (A4)
/A_D5: U3.17 (Q5), U5.7 (A5), U7.17 (D5), U22.13 (B5), U45.7 (A5)
/A_D6: U3.18 (Q6), U5.8 (A6), U7.18 (D6), U22.12 (B6), U45.8 (A6)
/A_D7: U3.19 (Q7), U5.9 (A7), U7.19 (D7), U22.11 (B7), U45.9 (A7)
/A_DB0: U1.33 (D0), U4.3 (D0), U5.18 (B0)
/A_DB1: U1.32 (D1), U4.4 (D1), U5.17 (B1)
/A_DB2: U1.31 (D2), U4.7 (D2), U5.16 (B2)
/A_DB3: U1.30 (D3), U4.8 (D3), U5.15 (B3)
/A_DB4: U1.29 (D4), U4.13 (D4), U5.14 (B4)
/A_DB5: U1.28 (D5), U4.14 (D5), U5.13 (B5)
/A_DB6: U1.27 (D6), U4.17 (D6), U5.12 (B6)
/A_DB7: U1.26 (D7), U4.18 (D7), U5.11 (B7)
/B_A0: U8.9 (A0), U20.18 (B0), U33.10 (A0), U47.3 (D0)
/B_A1: U8.10 (A1), U20.17 (B1), U33.9 (A1), U47.4 (D1)
/B_A2: U8.11 (A2), U20.16 (B2), U33.8 (A2), U47.7 (D2)
/B_A3: U8.12 (A3), U20.15 (B3), U33.7 (A3), U47.8 (D3)
/B_A4: U8.13 (A4), U20.14 (B4), U33.6 (A4), U47.13 (D4)
/B_A5: U8.14 (A5), U20.13 (B5), U33.5 (A5), U47.14 (D5)
/B_A6: U8.15 (A6), U20.12 (B6), U33.4 (A6), U47.17 (D6)
/B_A7: U8.16 (A7), U20.11 (B7), U33.3 (A7), U47.18 (D7)
/B_A8: U8.17 (A8), U21.18 (B0), U33.25 (A8), U42.3 (D0)
/B_A9: U8.18 (A9), U21.17 (B1), U33.24 (A9), U42.4 (D1)
/B_A10: U8.19 (A10), U21.16 (B2), U33.21 (A10), U42.7 (D2)
/B_A11: U8.20 (A11), U21.15 (B3), U33.23 (A11), U42.8 (D3)
/B_A12: U8.22 (A12), U21.14 (B4), U33.2 (A12), U42.13 (D4)
/B_A13: U8.23 (A13), U21.13 (B5), U33.26 (A13), U42.14 (D5)
/B_A14: U8.24 (A14), U21.12 (B6), U33.1 (A14), U42.17 (D6)
/B_A15: R7.1, U8.25 (A15), U14.9, U17.1, U42.18 (D7)
/B_A16: U9.2 (O0), U35.2 (P0), U41.3 (D0)
/B_A17: U9.5 (O1), U35.4 (P1), U41.4 (D1)
/B_A18: U9.6 (O2), U35.6 (P2), U41.7 (D2)
/B_A19: U9.9 (O3), U35.8 (P3), U41.8 (D3)
/B_A20: U9.12 (O4), U35.11 (P4), U41.13 (D4)
/B_A21: U9.15 (O5), U35.13 (P5), U41.14 (D5)
/B_A22: U9.16 (O6), U35.15 (P6), U41.17 (D6)
/B_A23: U9.19 (O7), U35.17 (P7)
/B_D0: U10.2 (A0), U22.2 (A0), U33.11 (Q0), U43.3 (D0), U44.2 (O0)
/B_D1: U10.3 (A1), U22.3 (A1), U33.12 (Q1), U43.4 (D1), U44.5 (O1)
/B_D2: U10.4 (A2), U22.4 (A2), U33.13 (Q2), U43.7 (D2), U44.6 (O2)
/B_D3: U10.5 (A3), U22.5 (A3), U33.15 (Q3), U43.8 (D3), U44.9 (O3)
/B_D4: U10.6 (A4), U22.6 (A4), U33.16 (Q4), U43.13 (D4), U44.12 (O4)
/B_D5: U10.7 (A5), U22.7 (A5), U33.17 (Q5), U43.14 (D5), U44.15 (O5)
/B_D6: U10.8 (A6), U22.8 (A6), U33.18 (Q6), U43.17 (D6), U44.16 (O6)
/B_D7: U10.9 (A7), U22.9 (A7), U33.19 (Q7), U43.18 (D7), U44.19 (O7)
/B_DB0: RN1.9 (R8), U8.33 (D0), U9.3 (D0), U10.18 (B0)
/B_DB1: RN1.8 (R7), U8.32 (D1), U9.4 (D1), U10.17 (B1)
/B_DB2: RN1.7 (R6), U8.31 (D2), U9.7 (D2), U10.16 (B2)
/B_DB3: RN1.6 (R5), U8.30 (D3), U9.8 (D3), U10.15 (B3)
/B_DB4: RN1.5 (R4), U8.29 (D4), U9.13 (D4), U10.14 (B4)
/B_DB5: RN1.4 (R3), U8.28 (D5), U9.14 (D5), U10.13 (B5)
/B_DB6: RN1.3 (R2), U8.27 (D6), U9.17 (D6), U10.12 (B6)
/B_DB7: RN1.2 (R1), U8.26 (D7), U9.18 (D7), U10.11 (B7)
/D0: J1.1, J2.1, J3.1, J4.1, J5.22, J6.22, J13.1, RN2.9 (R8), U11.18 (D0), U43.2 (O0), U44.3 (D0), U45.18 (B0), U49.3 (D0)
/D1: J1.2, J2.2, J3.2, J4.2, J5.23, J6.23, J13.2, RN2.8 (R7), U11.19 (D1), U43.5 (O1), U44.4 (D1), U45.17 (B1), U49.4 (D1)
/D2: J1.3, J2.3, J3.3, J4.3, J5.24, J6.24, J13.3, RN2.7 (R6), U11.20 (D2), U43.6 (O2), U44.7 (D2), U45.16 (B2)
/D3: J1.4, J2.4, J3.4, J4.4, J5.25, J6.25, J13.4, RN2.6 (R5), U11.21 (D3), U43.9 (O3), U44.8 (D3), U45.15 (B3)
/D4: J1.5, J2.5, J3.5, J4.5, J5.26, J6.26, J13.5, RN2.5 (R4), U11.22 (D4), U43.12 (O4), U44.13 (D4), U45.14 (B4)
/D5: J1.6, J2.6, J3.6, J4.6, J5.27, J6.27, J13.6, RN2.4 (R3), U11.23 (D5), U43.15 (O5), U44.14 (D5), U45.13 (B5)
/D6: J1.7, J2.7, J3.7, J4.7, J5.28, J6.28, J13.7, RN2.3 (R2), U11.24 (D6), U43.16 (O6), U44.17 (D6), U45.12 (B6)
/D7: J1.8, J2.8, J3.8, J4.8, J5.29, J6.29, J13.8, RN2.2 (R1), U11.25 (D7), U43.19 (O7), U44.18 (D7), U45.11 (B7)
CACHE_CS: U14.10, U18.10
CACHE_~CS: U16.13, U18.11, U22.19 (CE), U32.7 (~Y7)
CLK: J1.20, J2.20, J5.32, J6.32, J14.1, U1.37 (PHI2), U2.4, U2.13, U8.37 (PHI2), U11.27 (PHI2), U16.5, U16.10, U18.5, U25.10, U27.1, U27.4, U27.13, U46.1, Y1.5 (OUT)
EXT: U14.1, U16.12, U23.1 (EN), U24.19 (P=R), U36.3, U41.1 (OE), U42.1 (OE), U47.1 (OE)
GND: C1.1, C2.1, C3.1, C4.1, C5.1, C6.1, C7.1, C8.1, C9.1, C10.1, C11.2, C12.2, C13.2, C14.2, C15.2, C16.2, C17.2, C18.2, C19.2, C20.1, C21.1, C22.1, C24.1, C25.2, C26.1, C27.1, C28.1, C29.2, C30.1, C31.1, C32.1, C33.1, C34.1, C35.1, C36.1, C37.1, C38.2, C39.2, C40.2, C41.2, C42.2, C43.2, C44.2, C45.1, J1.21, J2.21, J3.17, J4.17, J5.33, J6.33, J8.1, J9.2, J10.2, J11.2, J14.8, J17.1, J18.1, J19.1, J20.1, Q1.1 (E), R5.2, R7.2, R10.1, R13.1, R15.2, R16.2, R17.2, R18.2, R20.1, RN1.1 (common), RN2.1 (common), SW1.2, U1.21 (GND), U2.7 (GND), U3.14 (GND), U4.1 (OE), U4.10 (GND), U5.10 (GND), U7.14 (GND), U8.21 (GND), U9.1 (OE), U9.10 (GND), U10.10 (GND), U11.1 (GND), U13.2 (GND), U14.7 (GND), U14.12, U14.13, U15.1 (G), U15.5 (R1), U15.7 (R2), U15.9 (R3), U15.10 (GND), U15.12 (R4), U15.14 (R5), U15.16 (R6), U15.18 (R7), U16.7 (GND), U17.7 (GND), U17.9, U17.11, U17.13, U18.7 (GND), U19.7 (GND), U20.10 (GND), U21.10 (GND), U22.10 (GND), U23.4 (EN), U23.5 (D), U23.7 (GND), U23.9 (D), U23.10 (EN), U23.12 (D), U23.13 (EN), U24.1 (G), U24.3 (R0), U24.5 (R1), U24.7 (R2), U24.9 (R3), U24.10 (GND), U24.12 (R4), U24.14 (R5), U24.16 (R6), U24.18 (R7), U25.7 (GND), U26.8 (GND), U27.7 (GND), U28.2 (GND), U29.2 (GND), U30.2 (GND), U31.2 (GND), U32.4 (~E0), U32.8 (GND), U33.14 (GND), U35.1 (G), U35.3 (R0), U35.5 (R1), U35.7 (R2), U35.9 (R3), U35.10 (GND), U35.12 (R4), U35.14 (R5), U35.16 (R6), U35.18 (R7), U36.7 (GND), U38.10 (GND), U39.10 (GND), U40.10 (GND), U41.10 (GND), U42.10 (GND), U43.10 (GND), U44.10 (GND), U45.10 (GND), U46.7 (GND), U47.10 (GND), U49.1 (OE), U49.7 (D2), U49.8 (D3), U49.10 (GND), U49.13 (D4), U49.14 (D5), U49.17 (D6), U49.18 (D7), Y1.4 (GND)
unnamed: C12.1, R4.2, U18.1
unnamed: D1.1 (K), R5.1
unnamed: D2.1 (K), R10.2
unnamed: D3.2 (A), R11.2
unnamed: D3.1 (K), Q1.3 (C)
unnamed: D4.2 (A), J1.24
unnamed: D4.1 (K), R15.1
unnamed: D5.2 (A), J2.24
unnamed: D5.1 (K), R16.1
unnamed: D6.2 (A), J3.20
unnamed: D6.1 (K), R17.1
unnamed: D7.2 (A), J4.20
unnamed: D7.1 (K), R18.1
unnamed: D8.2 (A), U11.11 (~DTR)
unnamed: D8.1 (K), R20.2
unnamed: D9.2 (A), J9.1
unnamed: D9.1 (K), U13.1 (VI)
unnamed: J1.13, J2.13, J3.11, J4.11, U26.15 (~Y0)
unnamed: J1.14, J2.14, J3.12, J4.12, U26.14 (~Y1)
unnamed: J1.15, J2.15, J3.13, J4.13, U26.13 (~Y2)
unnamed: J1.16, J2.16, J3.14, J4.14, U26.12 (~Y3)
unnamed: J1.23, U28.3 (VO)
unnamed: J2.23, U29.3 (VO)
unnamed: J3.19, U30.3 (VO)
unnamed: J4.19, U31.3 (VO)
unnamed: J5.30, U32.14 (~Y1)
unnamed: J6.30, U32.13 (~Y2)
unnamed: Q1.2 (B), R14.2
unnamed: R2.2, U1.3 (ABORT)
unnamed: R3.1, U1.36 (BE)
unnamed: R1.2, U1.2 (RDY)
unnamed: U3.20 (~CS), U25.12
unnamed: U3.22 (~OE), U7.22 (~OE), U16.6
unnamed: U3.27 (~WE), U27.11
unnamed: U7.20 (~CS), U25.6
unnamed: R12.2, U8.3 (ABORT)
unnamed: R21.2, U8.2 (RDY)
unnamed: U2.3, U8.40 (~RESET)
unnamed: R19.2, U11.7 (XLT0), Y2.1
unnamed: C25.1, R19.1, U11.6 (XTLI), Y2.2
unnamed: U14.3, U18.9
unnamed: U14.8, U27.9
unnamed: U15.19 (P=R), U26.4 (~E0), U32.6 (E2)
unnamed: U2.6, U16.1
unnamed: U16.2, U36.8
unnamed: U16.9, U46.8
unnamed: U17.2, U46.13
unnamed: U17.4, U27.10, U46.12
unnamed: U17.5, U25.8
unnamed: U18.2, U18.3
unnamed: U18.12, U25.11
unnamed: U2.11, U19.3 (C), U41.11 (LE), U42.11 (LE), U43.11 (LE), U47.11 (LE)
unnamed: U2.8, U19.11 (C)
unnamed: U25.1, U36.12
unnamed: U25.9, U36.2
unnamed: U18.8, U26.5 (~E1), U32.5 (~E1)
unnamed: U27.8, U33.20 (~CS)
unnamed: U27.3, U33.22 (~OE)
unnamed: U27.6, U33.27 (~WE)
unnamed: U2.12, U17.3, U35.19 (P=R)
unnamed: U16.3, U43.1 (OE)
unnamed: U44.11 (LE), U46.6
unnamed: U16.8, U44.1 (OE)
unnamed: U16.11, U45.19 (CE)
unnamed: U17.6, U49.11 (LE)
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

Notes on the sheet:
Debug header pins Addresses, data bus, control stuff

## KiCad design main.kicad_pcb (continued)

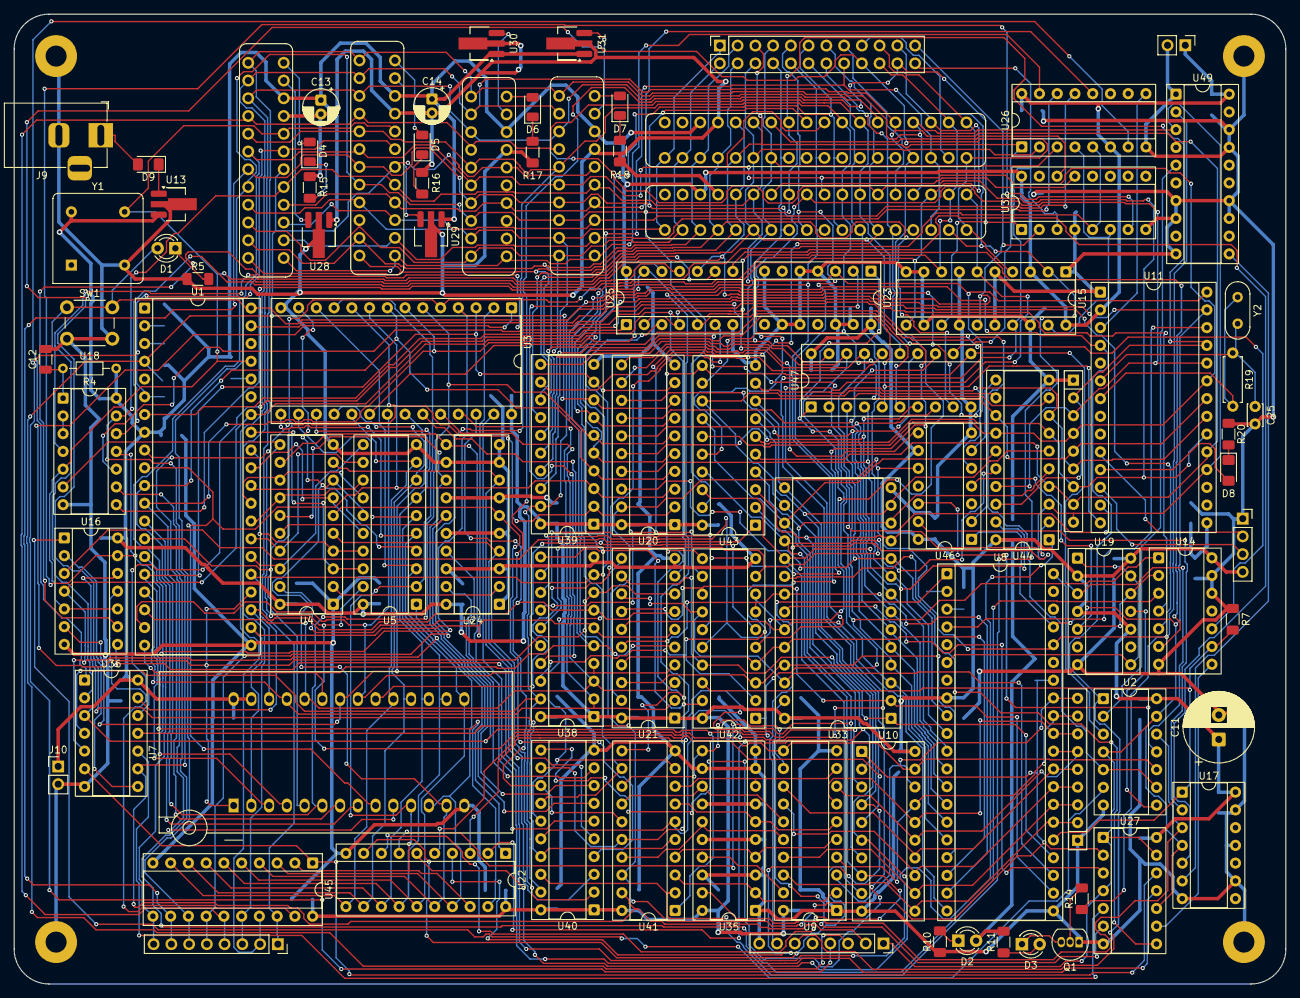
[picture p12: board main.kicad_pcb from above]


Board: 2 copper layers, 182.0 x 138.8 mm, 141 parts (48 on the bottom side), 206 nets.
